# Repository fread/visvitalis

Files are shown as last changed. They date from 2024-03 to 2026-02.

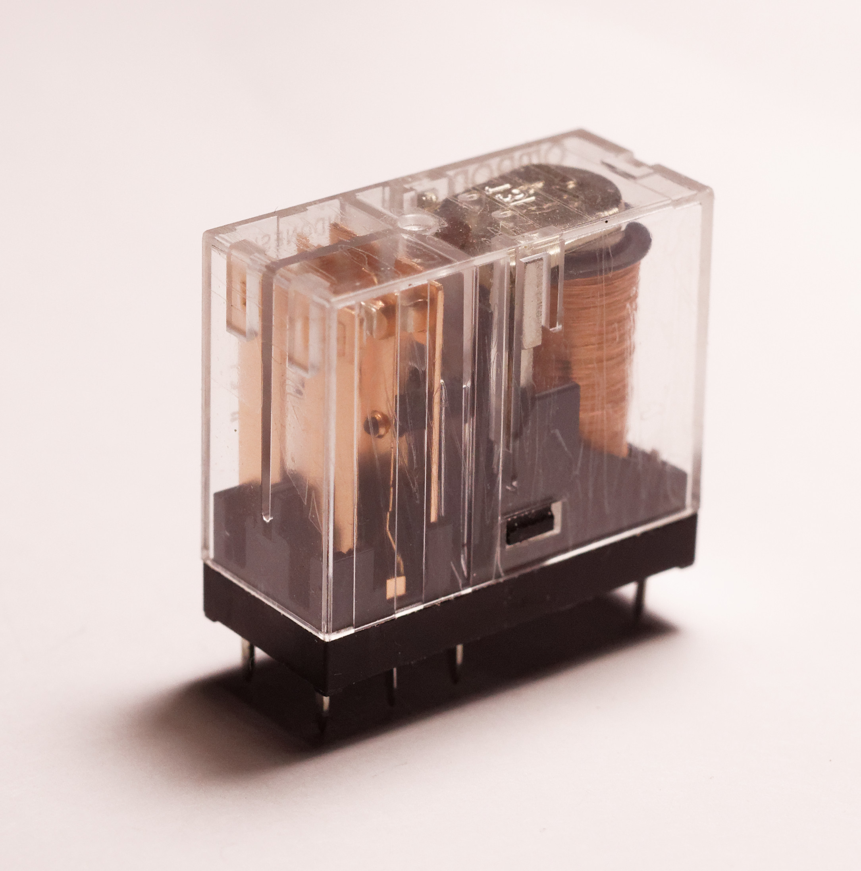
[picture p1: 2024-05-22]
docs/present/img/relay-transparent.jpg

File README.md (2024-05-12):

# vis vitalis - A very simple modular relay processor

This project contains plans for [PCB modules](/new-parts/) to build a relay processor, complete with [assembler](/assembler/) and [emulator](/emulator/).
While the actual processor is made out of relays (and the occasional diode), memory is emulated by ESP-based boards.
Their [firmware](/mem-esp-firmware/) also provides for loading programs and monitoring memory contents via a USB-TTY connection.

## Why though?

Processors are, fundamentally, not *that* complicated.
At any rate, you can build one out of much less than the billions of transistors required for a desktop CPU.
And it's a worthwhile endeavour, too, being actually able to understand a whole processor, albeit a very simple one.

### But why the name?

*vis vitalis*, meaning “force of life”, was a concept in early chemistry.
When it was first discovered that everything is made up of the same elements, people would not accept that this also applies to living beings.
Thus, they postulated the *vis vitalis* as a peculiar element present in everything living, unable to be replicated outside of biological processes.

Today, of course, we know that there is no fundamental difference at all between Turing-complete electronics and any others.

## The modules

Individually, each module performs a simple task – the trick is in how to put them together, for which see below.

In the module description, we use the usual tri-state convention for signal levels: `0` and `1` are signals actively driven low or high respectively, and `Z` is high-impedance, i. e. an unconnected signal.
In some cases, `0` and `Z` are interchangable but most modules require actively driven `0` signals at their inputs to work.

The modules are connected with 10-way ribbon cables carrying eight bits of data as well as 12V positive supply and ground.
Thus, not every module needs its own power supply connection.
Only modules which either draw a lot of current, or which require a stable supply, have a separate power connection.

### 8mux

An eight-bit multiplexer.
If the *select* input is `0` or `Z`, input *in 0* is connected to *out*.
If *select* is `1`, *in 1* is connected to *out*.

The multiplexer passes through signals between the connected terminals in both directions, though from a logical point of view the signals will almost always “flow” from *in* to *out*.

### add

Outputs the sum of *A in*, *B in*, and *carry in* on *A+B out* and *carry out*.
Note that the A operand and the carry bit is also required inverted (*A̅ in* and *c̅a̅r̅r̅y̅ in*).
All inputs must be `0` or `1`, and all outputs will be `0` or `1`.

For normal addition, set *carry in* to `0` and *c̅a̅r̅r̅y̅ in* to `1`.
If you want to subtract rather than add, invert the B and carry inputs (i. e. *carry in* = `1`, *c̅a̅r̅r̅y̅ in* = `0`).

#### Acknowledgement

This design of adder goes back to Konrad Zuse himself, I was made aware of it by the documentation of the
[RelaySBC](https://relaysbc.sourceforge.net/circuits.html) and this
[collection of relay circuits](https://tams.informatik.uni-hamburg.de/applets/hades/webdemos/05-switched/20-relays/zuseadd.html).
Its advantage is that there is no cascading from one relay to another.
All the relays switch in parallel and only steer the inverted and non-inverted signals around.

### clk

The clock generator.
With the values indicated in the schematic, and not populating R3–R6 (again, as indicated), the clock runs at a bit less than 1 Hz.
Populating R3 and R4 with a value of 1 to 15 kΩ slows down the clock, and populating R5 and R6 speeds it up.

#### Acknowledgement

This design was found with some shrewd (or so I'd like to think) internet research.
It originates from https://imgur.com/iKWSAM1.

### decode

In some sense, the instruction decoder is the heart of the processor, though this one mainly distributes the bits of the incoming instruction (*insn in*) to the control outputs (*control out*).

Other than that, it only performs a small assortment of simple logic:
- Relay K1 produces the clock pulses for the `p enable` and `a enable` outputs (to write the the corresponding registers)
- Relays K2, K3, and K5 implement a one-bit register for the carry flag to save the result of the last addition or subtraction.
  The carry register is written whenever the *adder* control signal is `1`.
- The other relays evaluate jump instructions.
  If the current instruction is a jump, they compare the current state of the flags (including the carry register) with the condition called for by the jump.
  They then output the decision to jump or to continue with the next instruction on *pc src out*.

Flag inputs must be `0` or `1`.
Instruction bit 5 must be `0` or `1`. 
The other bits may use `Z` instead of `0`, in which case the corresponding control output is also `Z`.

### disp

This module may be inserted into any data connection to view its current state.
It displays `Z` as `0`.

### flags

This module examines its input for three conditions, and outputs them:
- *odd*: The lowest bit of the input is set
- *sign*: The highest bit of the input is set
- *zero*: The input is zero

Inputs to this module may be `Z`, but then the *odd* and *sign* outputs will also be `Z`, which will not work with the *decode* module.

### inc

Increments the input *A in* and outputs the result on *A+1 out*.
Incrementers may be chained using the *carry in* and *carry out* connections.
The carry input of the first incrementer in a chain (or a standalone incrementer) must be tied to `1`.
This may be done by closing the solder bridge JP1.
In this case, *carry in* should be left unconnected.

All inputs must be `0` or `1`, and all outputs will be `0` or `1`.

### inv

The output *A̅ out* is the bitwise complement of *A in*.
Input values `0` and `Z` map to `1`, and `1` maps to `0`.

### jnc

Just a junction box.

### mem-esp

This module simulates both the program and the data memory.
From the processor's perspective, the program memory is an 8×16 bit ROM, and the data memory is an 8×8 bit RAM.
In addition, it has a USB-TTY connection, so that the memories may be loaded and monitored from a host computer.
Refer to the [documentation in the firmware directory](/mem-esp-firmware/README.md) for how to operate the TTY console.

The *addr in* input takes the address of the data to be read or written.
The *data1 i/o* connection operates either as an input or as an output, depending on the signal at the *w/r̅* input.
*data2 out* is always an output.

If the module is used as ROM, the input side of input no. 1 may not be populated (i. e., leaving out U3, U4, and R1–R16).
If the module is used as an 8×8 bit memory, the second output may not be populated (i. e., leaving out J8, U9, C9–C13).
In this case, the solder bridge JP4 needs to be closed in order to complete the SPI chain.

#### Operation

If the *w/r̅* input is `0` or `Z`, the module operates in read mode.
The output drivers at the *data1 i/o* and (if populated) *data2 out* connections will be active, and output the data found in memory at the address present at the *addr in* input.
The output changes asynchronously with the clock signal, but after a short delay to smooth out any glitches while switching.

If the *w/r̅* input is `1`, the module operates in write mode.
The output drivers are not active, and *data1 i/o* operates as an input.
At the clock's rising edge, the firmware starts sampling the state of *data1 i/o*.
At the clock's falling edge, it updated the memory contents.
For each bit, the most majority value seen in the samples is used, again to smooth out glitches and to account for propagation delays.
`Z` inputs are taken as `0`.

The switch between read and write mode occurs asynchronously.
As soon as the signal at the *w/r̅* input changes, the drivers are activated or deactivated.
Make sure that no signals are sent to the memory module in read mode.
This will lead to an overcurrent condition, and may damage parts.

### nor

This module implements a NOR gate.
For each bit of *A in* and *B in*, the corresponding output bit is `0` if any input is `1`, otherwise (both inputs `0` or `Z`) it is `1`.

### reg

This module is an eight-bit register.
While the *clock* input is `1`, it samples the value of the *in* input.
On the falling edge of the *clock* input (either to `0` or to `Z`), the sampled data is transferred to the buffer stage, and the outputs *out* and *o̅u̅t̅* (inverted) are updated.

The *override* input may be used to asnychronously set bits.
In normal operation, all bits should be `Z`.
Setting them to `0` or `1` causes the corresponding output to change immediately.
Since there are no resistors in the override path, bits should be set one or a few at a time.

### shr

This module shifts its input to the right by one bit.
It contains no logic.

### switch

This module may be used to provide inputs to a partial setup of other modules for testing purposes, or to override a register.
If it is used for overriding a register, it needs switches with a stable center position in order to provide `Z` outputs.

## The whole thing

[See the module schematic.](./docs/schematic.svg)

## Errata

- The LEDs specified on the *disp* and *switch* modules are way too bright in this configuration, even when increasing the series resistors to 2.2 kΩ.
- On the *reg* module, you may want to use larger input resistors (R9–R16) to lower the peak current at the beginning of the write cycle (clock rising edge).
- You may want to exchange the pin headers for control signals for sockets. Then you can use a simple wire in a pinch instead of requiring a jumper with sockets on either end.

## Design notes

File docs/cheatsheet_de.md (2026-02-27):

# Instruktionen

## Berechnen

In der folgenden Liste bedeutet:

* **A** der Inhalt des Akku-Registers
* **P** der Inhalt des Pointer-Registers
* **M[a]** der Inhalt des Speichers an der Adresse **a**

| Insn | Code | Beschreibung |
|---|---|---|
| `a2p` | P = A | Kopiere Akku in Pointer |
| `add x`  | A = A + M[x] | Addiere Variable zu Akku |
| `addi x` | A = A + x | Addiere Wert zu Akku |
| `addp` | A = A + M[P] | Addiere Pointer-Ziel zu Akku |
| `clm x`  | M[x] = 0 | Setze Variable auf 0 |
| `clmp` | M[P] = 0 | Setze Pointer auf 0 |
| `la x` | A = M[x] | Lade Variable in Akku |
| `lai x`  | A = x | Lade Wert in Akku |
| `lap` | A = M[P] | Lade Pointer-Ziel in Akku |
| `lp x` | P = M[x] | Lade Variable in Pointer |
| `lpi x`  | P = x | Lade Wert in Pointer |
| `lpp` | P = M[P] | Lade Pointer-Ziel in Pointer |
| `nor x`  | A = A NOR M[x] | Berechne NOR zwischen Akku und Variable |
| `nori x` | A = A NOR x | Berechne NOR zwischen Akku und Wert |
| `norp` | A = A NOR M[P] | Berechne NOR zwischen Akku und Pointer-Ziel |
| `nop` | | Tu nichts |
| `shr` | A = A >> 1 | Schiebe Akku ein Bit nach rechts |
| `shrs x` | M[x] = A = A >> 1 | Schiebe Akku ein Bit nach rechts und speichere in Variable |
| `sta x`  | M[x] = A | Speichere Akku in Variable |
| `stap` | M[P] = A | Speichere Akku in Pointer-Ziel |
| `stip x` | M[P] = x | Speichere Wert in Pointer-Ziel |
| `sub x`  | A = A - M[x] | Subtrahiere Variable von Akku |
| `subi x` | A = A - x | Subtrahiere Wert von Akku |
| `subp` | A = A - M[P] | Subtrahiere Pointer-Ziel von Akku |

## Springen

| Insn. | Beschreibung |
|---|---|
| `jmp x` | Springe zu x |
| `jc x`  | Springe zu x wenn Carry gesetzt |
| `jge x` | Springe zu x wenn Carry gesetzt |
| `jnc x` | Springe zu x wenn Carry nicht gesetzt |
| `jl x`  | Springe zu x wenn Carry nicht gesetzt |
| `js x`  | Springe zu x wenn Akku negativ ist |
| `jns x` | Springe zu x wenn Akku nicht negativ ist |
| `jz x`  | Springe zu x wenn Akku 0 ist |
| `jnz x` | Springe zu x wenn Akku nicht 0 ist |
| `jev x` | Springe zu x wenn Akku gerade ist |
| `jod x` | Springe zu x wenn Akku ungerade ist |
| `jp` | Springe zu P |
| `jcp` | Springe zu P wenn Carry gesetzt |
| `jncp`  | Springe zu P wenn Carry nicht gesetzt |
| `jsp` | Springe zu P wenn Akku negativ ist |
| `jnsp`  | Springe zu P wenn Akku nicht negativ ist |
| `jzp` | Springe zu P wenn Akku 0 ist |
| `jnzp`  | Springe zu P wenn Akku nicht 0 ist |
| `jevp`  | Springe zu P wenn Akku gerade ist |
| `jodp`  | Springe zu P wenn Akku ungerade ist |

## Illegale Instruktionen

Opcodes dürfen selbst zusammengebaut werden. Manche tun sinnvolle Dinge.

| Bit | wenn 0 | wenn 1 | Bemerkungen |
|-----|---|---|---|
| 7 | | Ergebnis in Speicher schreiben | wenn Bits (7, 6, 5) == 000: Sprung |
| 5 | | Ergebnis in P schreiben | |
| 5 | | Ergebnis in A schreiben | |
| 4 | Ergebnis von Operand/A  | Ergebnis von ALU | |
| 3 | Ergebnis von Operand | Ergebnis von A | wenn Bit 4 == 0 |
| 3 | ALU Shift/Add | ALU NOR/Subtract | wenn Bit 4 == 1 |
| 2 | ALU Shift/NOR | ALU Add/Subtract | 00: Shift, 01: Add, 10: NOR, 11: Sub |
| 1 | Operand aus Speicher | Operand aus Instruktion | "Immediate" |
| 0 | Adresse aus Instruktion | Adresse aus P | "indirekt" |

z. B. `0x5a 1`: P = A - 1

Bei Sprüngen gibt es keine illegalen Instruktionen, alle möglichen Instruktionen haben Mnemonics.

# Programmieren

## `uint8_t x;`
Adressen für Variablen mit `.equ` vergeben.
```asm
.equ x 23
```

## `x = 5;`
```asm
lai 5
sta x
```

## `x = y;`
```asm
la y
sta x
```

## `a = b + c`
```asm
la a
add b
sta c
```

## `if (x >= y) goto z;`
Für `jc` Und `jnc` gibt es die suggestiv benannten alternativen Mnemonics `jge` und `jl`:
```asm
la x
sub y
jge z
```

## `if (x < y) goto z;`
```asm
la x
sub y
jl z
  ```

## `while (x != 0) { xxx } yyy`
```asm
loop:
  la x
  jz end
  xxx
  jmp loop
end:
  yyy
  ...
```

## `x = a[i]`
```asm
la a
add i
a2p
lp
sta x
```

## `a[i] = x`
```asm
la a
add i
a2p
la x
stp
```

# Projektideen

* Lauflicht (hin und her?)
* Fibonacci
* Maximum suchen
* {mem,str}{cpy,chr,mem,str,...}
* Array umdrehen
* Multiplikation
* Binäre Suche
* Illegale Instruktionen ausprobieren
* Division
* Fizzbuzz
* Call/Return
* RPN-Evaluator

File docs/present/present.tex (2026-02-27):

\documentclass[t,aspectratio=169,usenames,dvipsnames]{beamer}

\graphicspath{{img/}}

\usepackage{mathspec}

\usepackage{algorithm}
\usepackage{algpseudocode}
\usepackage{booktabs}
\usepackage[ngerman]{babel}
\usepackage{cancel}
\usepackage{changepage}
\usepackage{collect}
\usepackage{comment}
\usepackage{csquotes}
\usepackage{float}
\usepackage{graphbox}
\usepackage{hyperref}
\usepackage{listings}
\usepackage{multimedia}
\usepackage{tikz}
\usepackage[table]{xcolor}
\usepackage{siunitx}
\usepackage{arev}
\usepackage{qrcode}

% \setmainfont{Libertinus Serif}
% \setsansfont{Libertinus Sans}
% \setmonofont{TeX Gyre Cursor Bold}
% \setmathfont[Digits]{Libertinus Sans}

\setmainfont{Liberation Serif}
\setsansfont{Liberation Sans}
\setmonofont{Liberation Mono}
\setmathfont[Digits]{Liberation Sans}

\usetheme{Madrid}
\usecolortheme{dove}
\setbeamercovered{invisible}
\setbeamercolor{alerted text}{fg=blue}

\setbeamertemplate{navigation symbols}{}

\newenvironment{itemblock}[1]{\begin{block}{#1}\begin{itemize}}{\end{itemize}\end{block}}
\newenvironment{withtitle}[1]{\begin{description}\item[#1]~\\}{\end{description}}

\newcommand{\todo}[1]{\colorbox{red}{\color{white}\bf TODO: #1}}
\newcommand{\dunno}[0]{\colorbox{red}{\color{white}\bf ???}}

\newcommand{\uexplain}[2]{\underbrace{\mathtt{#1}}_{\hidewidth \mathsf{#2}\hidewidth} \hskip 0.5em}
\newcommand{\oexplain}[2]{\overbrace{\mathtt{#1}}^{\hidewidth \mathsf{#2}\hidewidth} \hskip 0.5em}

\newcommand{\extraslide}{\textcolor{orange}{$\warning$}}

\definecollection{picture-sources}

\newcommand{\sourcedimage}[5][width=\textwidth,height=0.7\textheight,keepaspectratio]{%
  \begin{center}
    

    \expandafter\begin{collect}{picture-sources}{}{}
      \item[#3] \href{#4}{#4} \\ #5
    \end{collect}
  \end{center}
}

\newcommand{\imageframe}[4]{%
  {
    \setbeamercolor{background canvas}{bg=black}
    \begin{frame}[c,plain]
        \expandafter\begin{collect}{picture-sources}{}{}
        \item[#2] \href{#3}{#3} \\ #4
        \end{collect}
        \begin{tikzpicture}[remember picture,overlay]
          \node[at=(current page.center)] {
            
          };
        \end{tikzpicture}
    \end{frame}
  }
}

\lstset{basicstyle=\ttfamily}

\renewcommand{\algorithmicforall}{\textbf{for each}}

\title[~]{\Huge Computer selbst bauen}
\subtitle{}
\author[~]{andi $\langle$andi@entropia.de$\rangle$}
\date{}

\begin{document}

{
  \setbeamercolor{background canvas}{bg=black}
  \begin{frame}[plain]
    \begin{tikzpicture}[remember picture,overlay]
      \node[at=(current page.center)] {
        
      };
    \end{tikzpicture}
  \end{frame}
}

\begin{frame}
  \frametitle{Es ist kompliziert}

  \begin{columns}
    \begin{column}{.45\textwidth}
      \begin{center}
        \sourcedimage{zen2-die-shot}{Die Shot eines AMD Zen2}{https://en.wikipedia.org/wiki/File:Zen2\_Matisse\_Ryzen\_7nm\_Core\_Die\_shot.jpg}{Fritzchens Fritz, 2019. CC-0.}
        \emph{AMD Zen 2 \enquote{Matisse}}
      \end{center}
    \end{column}
    \begin{column}{.45\textwidth}
      \begin{itemize}
      \item \qty{4800000000} Transistoren
      \item Taktzeit:\\
        \qty{0.2}{\nano\second} $\hat=$ \qty{6.4} Licht-cm $\approx$ \qty{4} Strom-cm
      \end{itemize}
    \end{column}
  \end{columns}
\end{frame}

\begin{frame}
  \frametitle{Es geht einfacher}

  \begin{columns}
    \begin{column}{.45\textwidth}
      \sourcedimage{relay-transparent}{Transparentes Relais}{https://commons.wikimedia.org/wiki/File:Omron\_G2R-2-24V\_relay\_04.jpg}{Retired electrician, 2022. CC-0.}
    \end{column}
    \begin{column}{.45\textwidth}
      \begin{itemize}
      \item \qty{120} Relais
      \item Takt: $\approx$ \qty{1}{\second}
      \end{itemize}

      \bigskip\pause

      \begin{itemize}
      \item auch binäre Schaltung (sort of)
      \item Kann auch Logik-Gates implementieren
      \item Details: ignorieren wir
      \end{itemize}
    \end{column}
  \end{columns}
\end{frame}

\begin{frame}
  \frametitle{Thinking with Modules}

  \strut{}\alt<2>{So sehen wir es:}{So sieht es eigentlich aus:}

  \bigskip

  \alt<2>{
    \centering

    \bigskip

    \begin{itemize}
    \item 8 Signale auf einmal\\
      \emph{nur} in unserem Kopf eine Zahl, Adresse, \ldots
    \item Funktionalität in Module zusammengefasst\\
      Bits rein, Bits raus, dazwischen Magie
    \end{itemize}
  }{
    \centering
  }

\end{frame}

% \begin{frame}
%   \frametitle{0, 1, Logik}

%   \begin{center}
%     MOSFET, BJT, Röhren, Ringkerne, Opamps, Relais, Hydraulik, Lochbleche, \ldots

%     \textit{Alles das Gleiche und sowieso nur Gefrickel!}
%   \end{center}

%   \begin{columns}[t]
%     \begin{column}{.45\textwidth}
%       \begin{block}{Signale}
%         \begin{itemize}
%         \item binärer Rechner $\Rightarrow$ 0 und 1
%         \item Signalübertragung (also Kabel \ldots)
%         \end{itemize}
%       \end{block}
%     \end{column}
%     \begin{column}{.45\textwidth}
%       \begin{block}{Gates}
%         Beliebige Gates sind erlaubt, spezifiziert durch \enquote{kleine} I/O-Tabelle

%         \begin{center}
%           \begin{tabular}{ccc}
%             X & Y & out \\
%             \midrule
%             0 & 0 & 1 \\
%             0 & 1 & 0 \\
%             1 & 0 & 0 \\
%             1 & 1 & 0 \\
%           \end{tabular}
%         \end{center}
%       \end{block}
%     \end{column}
%   \end{columns}
% \end{frame}

% \begin{frame}
%   \frametitle{Busse}

%   \begin{columns}[T]
%     \begin{column}{.45\textwidth}
%       \begin{itemize}
%       \item Signale gehören zusammen und tun \enquote{das Gleiche}
%       \item übersichtlicher mit einer Linie\\
%         (1 fette Linie $\hat=$ 8 dünne)\\
%         und einem Gate
%       \item nur (!) in unserem Kopf:\\
%         Zahl, Adresse, Instruktion \ldots
%       \end{itemize}
%     \end{column}

%     \begin{column}{.45\textwidth}
%       \centering\includegraphics[height=.75\textheight]{nor-bus.pdf}
%     \end{column}
%   \end{columns}
% \end{frame}

\begin{frame}[c]
  \frametitle{Rechnen ist nicht schwer}

  \strut{}Zwei Eingänge für zwei Operanden, im Prinzip nicht schwieriger, nur mehr Hardware

  \bigskip

  \centering
\end{frame}

\begin{frame}
  \frametitle{\extraslide{} OK, vielleicht nicht ganz so simplel}

  \begin{columns}
    \begin{column}{.45\textwidth}
      \begin{align*}
        0 + 0 + 0 = 00 \\
        0 + 0 + 1 = 01 \\
        0 + 1 + 0 = 01 \\
        1 + 0 + 0 = 01 \\
        1 + 1 + 0 = 10 \\
        \textcolor<2->{RoyalBlue}{1 + 0 + 1 = 10} \\
        0 + 1 + 1 = 10 \\
        1 + 1 + 1 = 11
      \end{align*}

      Drei Eingänge, zwei Ausgänge, aber auch nur ein Gate!
    \end{column}
    \begin{column}{.45\textwidth}
      \begin{center}
        \alt<2->{
          \begin{tabular}{ccccccccc}
            & 0 & 0 & 1 & 1 & \cellcolor{SkyBlue}1 & 1 & 1 & 0 \\
            + & 0 & 0 & 0 & 1 & \cellcolor{SkyBlue}0 & 1 & 0 & 1 \\
            &   &   & \scriptsize{1}  & \cellcolor{SkyBlue}\scriptsize{1}  & \cellcolor{SkyBlue}\scriptsize{1}  &   &   &   \\
            \hline
            & 0 & 1 & 0 & 1 & \cellcolor{SkyBlue}0 & 0 & 1 & 1
          \end{tabular}
        }{
          \begin{tabular}{ccccccccc}
            & 0 & 0 & 1 & 1 & 1 & 1 & 1 & 0 \\
            + & 0 & 0 & 0 & 1 & 0 & 1 & 0 & 1 \\
            &   &   & \scriptsize{1}  & \scriptsize{1}  & \scriptsize{1}  &   &   &   \\
            \hline
            & 0 & 1 & 0 & 1 & 0 & 0 & 1 & 1
          \end{tabular}
        }

        \bigskip

        \uncover<3>{
          
        }
      \end{center}
    \end{column}
  \end{columns}

\end{frame}

\begin{frame}
  \frametitle{\extraslide{} Auftritt Zuse}

  \begin{columns}[T]
    \begin{column}{.50\textwidth}
      \begin{tabular}{ccc@{\hskip 2em}c@{\hskip 2em}cc}
        \toprule
        $A$ & $B$ & $C_{\text{in}}$ & \uncover<2->{$A \oplus B$} & $A + B + C_{\text{in}}$ & $C_{\text{out}}$ \\
        \midrule
        0 & 0 & 0 & \uncover<2->{0} & \alt<3->{$C_{in}$}{0}      & \alt<4->{$A$}{0}      \\
        0 & 0 & 1 & \uncover<2->{0} & \alt<3->{$C_{in}$}{1}      & \alt<4->{$A$}{0}      \\
        0 & 1 & 0 & \uncover<2->{1} & \alt<3->{$\neg C_{in}$}{1} & \alt<4->{$C_{in}$}{0} \\
        0 & 1 & 1 & \uncover<2->{1} & \alt<3->{$\neg C_{in}$}{0} & \alt<4->{$C_{in}$}{1} \\
        1 & 0 & 0 & \uncover<2->{1} & \alt<3->{$\neg C_{in}$}{1} & \alt<4->{$C_{in}$}{0} \\
        1 & 0 & 1 & \uncover<2->{1} & \alt<3->{$\neg C_{in}$}{0} & \alt<4->{$C_{in}$}{1} \\
        1 & 1 & 0 & \uncover<2->{0} & \alt<3->{$C_{in}$}{0}      & \alt<4->{$A$}{1} \\
        1 & 1 & 1 & \uncover<2->{0} & \alt<3->{$C_{in}$}{1}      & \alt<4->{$A$}{1}      \\
        \bottomrule
      \end{tabular}
    \end{column}
    \begin{column}{.45\textwidth}
      \begin{itemize}
      \item Wie geht das besser?
        \pause
      \item Es muss etwas mit XOR zu tun haben
        \pause
      \item $A + B = \begin{cases}
                       C_{in} & A \oplus B = 0 \\
                       \neg C_{in} & A \oplus B = 1 \\
                     \end{cases}$
        \pause
      \item $C_{out} = \begin{cases}
                         A & A \oplus B = 0 \\
                         C_{in} & A \oplus B = 1 \\
                       \end{cases}$
        \pause
        \bigskip
      \item Nur $A$ und $B$ fließen in Logik ein!
      \item Kein Ripple mehr!
      \end{itemize}
    \end{column}
  \end{columns}
\end{frame}

\begin{frame}
  \frametitle{Ist das nicht schon alles?}

  \begin{columns}
    \begin{column}{.45\textwidth}
      \begin{center}
        

        \[ x_1 = \frac{-b + \sqrt{b^2 - 4ac}}{2a} \]
      \end{center}
    \end{column}
    \begin{column}{.45\textwidth}
      \uncover<2->{
        Nein, es fehlt \ldots
        \begin{itemize}
        \item \textbf{Auswahl}\\
          $x_2$ ohne Neuverkabeln
        \item \textbf{Speicher}\\
          $a$, $b$, $c$ weg $\Rightarrow$ $x$ weg\quad :(
        \item \textbf{Programm}\\
          \texttt{goto}, \texttt{if}, \texttt{while}, \texttt{for}, \texttt{func}, \ldots
        \end{itemize}
      }
    \end{column}
  \end{columns}
\end{frame}

\begin{frame}
  \frametitle{1/3: Auswahl}

  Wichtigstes Modul: \textbf{Multiplexer} (Spitzname: Mux)

  \begin{columns}
    \begin{column}{.45\textwidth}
      \begin{center}
        
      \end{center}
    \end{column}
    \begin{column}{.45\textwidth}

      \textbf{s} ist nur ein Bit
      \begin{itemize}
      \item $\mathbf{s} = 0$:\\
        Eingang 0 mit Ausgang verbunden
      \item $\mathbf{s} = 1$:\\
        Eingang 1 mit Ausgang verbunden
      \end{itemize}

      \bigskip

      Von zwei Bytes eins auswählen

    \end{column}
  \end{columns}
\end{frame}

\begin{frame}
  \frametitle{Fast eine ALU}

    \begin{columns}[T]
    \begin{column}{.45\textwidth}
        \only<1>{}
        \only<2>{}
    \end{column}
    \begin{column}{.45\textwidth}
      Prinzip: Erst rechnen, dann aussuchen

      \bigskip

      \textbf{Kontrollsignale}

      \begin{itemize}
      \item Steuern Datenfluss, bei uns vor allem an Multiplexern
      \item Jetzt: \enquote{Schalter}
      \item Später: Programmieren
      \end{itemize}

      \bigskip

      \only<2>{
        \begin{itemize}
        \item Mehr Möglichkeiten: Mux-Baum bauen
        \item nicht \emph{ganz} realistisch
        \end{itemize}
      }
  \end{column}
  \end{columns}
\end{frame}

\begin{frame}
  \frametitle{2/3: Speicher}

  Details ignorieren wir wieder (irgendwas mit Kondensatoren und Hysterese)

  \bigskip

  

  \bigskip

  \enquote{write}-Signal wird Systemtakt/-clock sein
\end{frame}

\begin{frame}[c]
  \frametitle{\extraslide{} Doch mit Details}

  \begin{columns}[c]
    \begin{column}{.45\textwidth}
      
    \end{column}
    \begin{column}{.45\textwidth}
      \begin{itemize}
      \item Was ist Hysterese?
        \begin{itemize}
        \item über ca. 9~V: an
        \item unter ca. 2~V: aus
        \item dazwischen: nichts passiert
        \end{itemize}

      \item K2 auf ca. ½ VCC \\
        $\Rightarrow$ hält Zustand

        \bigskip

      \item Clock-Phasen:
        \begin{itemize}
        \item High: d\_in lädt C1 auf GND/VCC
        \item Low: Puls von C1 bringt K2 über 9~V oder unter 2~V
        \end{itemize}
      \end{itemize}
    \end{column}
  \end{columns}

\end{frame}

\begin{frame}
  \frametitle{Speicher × 8}

  \begin{columns}[T]
    \begin{column}{.45\textwidth}
      
    \end{column}
    \begin{column}{.45\textwidth}
      \begin{itemize}
      \item erstes Modul mit Takt\\
        (Kennzeichnung mit {\Large$\triangleright$})
      \item nicht immer jedes Register überschreiben\\
        $\Rightarrow$ \emph{Clock-Gate}
      \item Kontrollsignal \enquote{A enable}
      \end{itemize}
    \end{column}
  \end{columns}

\end{frame}

\begin{frame}
  \frametitle{\emph{mehr} Speicher}

  \begin{columns}
    \begin{column}{.7\textwidth}
      
    \end{column}
    \begin{column}{.25\textwidth}
      \uncover<2>{Das wird \emph{groß}...}
    \end{column}
  \end{columns}

\end{frame}

\begin{frame}
  \frametitle{Leider gecheatet}

  \begin{itemize}
  \item 1 Register ${} \mathrel{\hat=} \qty{5}{\centi\metre} \times \qty{10}{\centi\metre}$
  \item 256 Register ($16 \times 16$) ${} \mathrel{\hat=} \qty{80}{\centi\metre} \times \qty{160}{\centi\metre}$
  \item \ldots von den Muxen ganz zu schweigen
  \end{itemize}

  \bigskip

  $\Rightarrow$ Geht nur mit ICs

  \bigskip

  Außerdem:
  \begin{itemize}
  \item Programme Laden
  \item Debugging
  \item Speichermonitor
  \end{itemize}

\end{frame}

\begin{frame}
  \frametitle{RAM}

  \begin{itemize}
  \item In jedem Takt Lesen \emph{oder} Schreiben
  \item Daten-Anschluss ist bidirektional $\Rightarrow$ etwas verdächtiger Mux
  \end{itemize}

  \bigskip

  \begin{center}
    
  \end{center}
\end{frame}

\begin{frame}
  \frametitle{Jetzt geht's los}

  Alles beisammen:

  \bigskip

  \renewcommand{\arraystretch}{3.5}

  \begin{tabular}{clc>{\qquad}clc}
    \setcounter{enumi}{1}\usebeamertemplate{enumerate item}
    & Berechnungen
    & 
    & \setcounter{enumi}{1}\usebeamertemplate{enumerate item}
    & Speicher
    &  \\

    \setcounter{enumi}{2}\usebeamertemplate{enumerate item}
    & Multiplexer
    & 
    & \setcounter{enumi}{5}\usebeamertemplate{enumerate item}
    & \multicolumn{2}{l}{???\qquad{}\uncover<2>{\textbf{Sie befinden sich hier}}}
    \\

    \setcounter{enumi}{3}\usebeamertemplate{enumerate item}
    & Register
    & 
    & \setcounter{enumi}{6}\usebeamertemplate{enumerate item}
    & \cancel{Profit} Prozessor
    &
  \end{tabular}
\end{frame}

\begin{frame}
  \frametitle{\extraslide{} Assembler}

  Wie sollen Instruktionen aussehen?
  \begin{itemize}
  \item Wie RISC (ARM, RISC-V, MIPS, SPARC, \ldots): \texttt{add r3, r2, r1}\\
    16/32 Register, 3 Register in jeder Instruktion, Laden/Speichern anderes Format
  \item Wie x86: \texttt{addq \%rsi, 42(\%rbx, \%rcx, 4)}\\
    Nein
  \item Wie 6502: \texttt{lda \$23; adc \$42}\\
    4(?) Register, 1 Operand, (fast) immer genau ein Speicherzugriff\\
    \pause
    \textbf{Das klingt gut!}
  \end{itemize}

  \bigskip

  Unser Plan:
  \begin{itemize}
  \item Opcode + 1 Operand
  \item wenige Register
  \item einmal Laden/Speichern pro Instruktion
  \end{itemize}

\end{frame}

\begin{frame}
  \frametitle{Akkumulator-Architektur}

  \begin{itemize}
  \item Instruktion = Operation + Operand
  \item \emph{ein einziges} Register (\texttt{A})
  \item alle Berechnungen \enquote{\texttt{A} = \texttt{A} $\circledast$ Speicher}
  \item ein Speicherzugriff pro Instruktion $\checkmark$
  \end{itemize}

  \bigskip

  \texttt{z = x + y;} wird zu

  \bigskip

  {\Large
    \texttt{load~~\&x} \qquad \texttt{A = x};\\
    \texttt{add~~~\&y} \qquad \texttt{A = A + y;}\\
    \texttt{store~\&z} \qquad \texttt{z = A;}\\
  }
\end{frame}

\begin{frame}
  \frametitle{\extraslide{} Plus/Minus}

  Addition und Subtraktion sind fast das Gleiche:
  \begin{align*}
    A - B &= A + (-B) \\
          &= A + (\neg B + 1) \\
          &= A \mathop{+} \neg B + 1_{\text{carry-in}}
  \end{align*}

  Also: $B$ negieren und ein Carry eingeben.
  \begin{align*}
    A \pm B &= A + \left\lbrace \begin{aligned} B \\ \neg B \end{aligned} \right\rbrace + \left\lbrace \begin{aligned} 0_{\text{carry-in}} \\ 1_{\text{carry-in}} \end{aligned} \right\rbrace\\
  \end{align*}
\end{frame}

\begin{frame}
  \frametitle{ALU-Aufbau: Rechnungen}

  \strut{}ALU + Write-Back in den Akkumulator

  \begin{center}
    
  \end{center}
\end{frame}

\begin{frame}
  \frametitle{ALU-Aufbau: \texttt{load}}

  \strut{}Ein Weg an der ALU vorbei um Daten in A zu laden

  \begin{center}
    
  \end{center}
\end{frame}

\begin{frame}
  \frametitle{ALU-Aufbau: \texttt{store}}

  \strut{}Operanden kommen aus dem Speicher, Ergebnisse müssen dahin zurück

  \begin{center}
    
  \end{center}
\end{frame}

\begin{frame}
  \frametitle{Immediates}

  Konstanten sind auch wichtig:
  \begin{itemize}
  \item \texttt{answer = secret + 19;}
  \item \texttt{start = 0;}
  \item \texttt{i++}
  \end{itemize}

  \bigskip

  In Assembler \enquote{Immediate}. Operand als Wert, nicht als Adresse

  \medskip

  {\Large
    \begin{tabular}{l@{\hskip 4em}l}
      \texttt{add 19} & \texttt{addi 19} \\
      \texttt{load 0} & \texttt{loadi 0} \\
    \end{tabular}
  }

  \bigskip

  \pause
  Wir brauchen noch ein Mux \ldots\ (es wird nicht das Letzte sein)
\end{frame}

\begin{frame}
  \frametitle{Immediates}

  \strut{}Operand direkt in die ALU geben

  \begin{center}
    
  \end{center}
\end{frame}

\begin{frame}
  \frametitle{Pointer}

  Manchmal sind Adressen nicht konstant:
  \begin{itemize}
  \item \texttt{int *p = lol(); int x = *p;}
  \item \texttt{cpu->bits = 8;}
  \item \texttt{dinge[i] = d;}
  \end{itemize}

  \bigskip

  Adresse in A berechnen und dann Laden/Speichern?\\
  Leider nein: \texttt{*p = x;} braucht \texttt{p} und \texttt{x} gleichzeitig

  \bigskip
  \pause

  Wir brauchen noch ein Mux und ein \emph{Register} \ldots\ (zum Glück das Vorletzte)

\end{frame}

\begin{frame}
  \frametitle{Pointer}

  \strut{}Zweites Register mit Write-Back, Auswahl der Datenadresse

  \begin{center}
    
  \end{center}
\end{frame}

\begin{frame}
  \frametitle{Fertig ist der \emph{Data-Path}}

  \strut{}\alt<2>{\cancel{9} 8}{9} Kontrollsignale steuern alles

  \begin{center}
    \alt<2>{}{}
  \end{center}
\end{frame}

\begin{frame}
  \frametitle{Plötzlich Maschinencode}

  {\centering
    \begin{tikzpicture}
      \node[draw,thick,minimum width=5em,minimum height=5em,align=center] at (0,0) {\footnotesize Speicher\\\footnotesize schreiben};
      \node[draw,thick,minimum width=5em,minimum height=5em,align=center] at (5em,0) {\footnotesize Reg. P\\\footnotesize schreiben};
      \node[draw,thick,minimum width=5em,minimum height=5em,align=center] at (10em,0) {\footnotesize Reg. A\\\footnotesize schreiben};
      \node[draw,thick,minimum width=5em,minimum height=5em,align=center] at (15em,0) {\footnotesize ALU\\\footnotesize benutzen};
      \node[draw,thick,minimum width=5em,minimum height=5em,align=center] at (20em,0) {\footnotesize A lesen\\\footnotesize ——\\\footnotesize \enquote{invertieren}};
      \node[draw,thick,minimum width=5em,minimum height=5em,align=center] at (25em,0) {\footnotesize Addierer\\\footnotesize benutzen};
      \node[draw,thick,minimum width=5em,minimum height=5em,align=center] at (30em,0) {\footnotesize Immediate};
      \node[draw,thick,minimum width=5em,minimum height=5em,align=center] at (35em,0) {\footnotesize Indirekt};
    \end{tikzpicture}
  }

  \begin{itemize}
  \item Eine Mux-Einstellung $\hat=$ ein Bit $\Rightarrow$ 8 in einem Byte zusammenfassen
  \item z.B. \texttt{add}: A schreiben, Ergebnis von der ALU, Addierer benutzen, sonst nichts\\
    $\Rightarrow \mathtt{add} = \text{0b00110100} = \text{0x34}$

    \medskip

  \item Zweites Byte für den Operanden: $\mathtt{add~42} = \text{0x342a}$
  \end{itemize}

  \bigskip

  \pause

  Eine Instruktion = 16 bit $\Rightarrow$ \textbf{Das können wir speichern!}
\end{frame}

\begin{frame}
  \frametitle{Programmspeicher}

  \strut{}Noch ein Speicher für das Programm (\enquote{Harvard})

  \begin{center}
    
  \end{center}
\end{frame}

\begin{frame}
  \frametitle{Program Counter}

  \strut{}Wenn wir doch nur automatisch zählen könnten~\ldots

  \begin{center}
    
  \end{center}
\end{frame}

\begin{frame}
  \frametitle{Sprünge}

  \strut{}Noch ein Mux, die Details sind kompliziert

  \begin{center}
    
  \end{center}
\end{frame}

\begin{frame}
  \frametitle{Was fehlt?}

  Was wir \enquote{Maschinencode} genannt haben sieht sehr nach \emph{Microcode} aus.
  \begin{itemize}
  \item Viele nutzlose Befehle: \enquote{Addiere \texttt{i} auf Inhalt der Adresse \texttt{i}}, anyone?\\
    \texttt{0x96 i}
  \item 3 Bit für Kombination aus \enquote{A schreiben}, \enquote{P schreiben}, \enquote{Speicher schreiben}\\
    Lieber 3 Bit für Auswahl von einer aus 8 Möglichkeiten!

  \end{itemize}

  \bigskip\pause

  \textbf{Decoding!} Kleinere Assembler-Befehle intern zu Steuersignalen auspacken
\end{frame}

\begin{frame}
  \frametitle{Ihr könnt das auch!}

  und zwar einfacher und besser
  \begin{itemize}
  \item Simulationen
    \begin{itemize}
    \item Paul Falstads Circuit Simulator
    \item Logisim(-Evolution)
    \item Turing Complete
    \end{itemize}
  \item FPGAs (jetzt auch in günstig und Open Source)
    \begin{itemize}
    \item Yosys OSS CAD Suite
    \end{itemize}
  \item Chips statt Relais
  \end{itemize}
\end{frame}

\begin{frame}
  \frametitle{Wie geht es weiter}

  Gerät ist im Nebenraum aufgebaut.

  \bigskip

  \begin{description}[ca. 20:00:]
  \item[Jetzt:] Q\&A
  \item[19:00:] Pause, Abendessen
  \item[ca. 20:00:] Assembler-Workshop
  \end{description}
\end{frame}

\begin{frame}
  \frametitle{Repository}
  \begin{center}
    \texttt{https://github.com/fread/visvitalis}

    \bigskip

    \qrcode[height=0.5\textheight]{https://github.com/fread/visvitalis}
  \end{center}
\end{frame}

\begin{frame}
  \frametitle{Assembler}

  \begin{itemize}
  \item Eine Instruktion pro Zeile
  \item (Mnemonic/Opcode) + Argument\\
    \texttt{~~lai 17}\\
    \texttt{~~addi 6}
  \item Werte definieren und benutzen (\texttt{\#define})\\
    \texttt{~~.equ x 2~~~~~~~~\# Adresse einer Variable}\\
    \texttt{~~.equ answer 42~~\# Konstante}\\
    \texttt{~~lai answer}\\
    \texttt{~~sta x~~~~~~~~~~~\# x = 42}\\
  \item Label vor Instruktion mit Doppelpunkt\\
    Expandiert zu Adresse der Instruktion\\
    \texttt{~~loop: subi 1}\\
    \texttt{~~~~~~~~jmp loop}
  \item Alles ein Namensraum
  \end{itemize}
\end{frame}

\begin{frame}
  \frametitle{Bildnachweis}
  \tiny
  \begin{description}
    \includecollection{picture-sources}
  \end{description}
\end{frame}

\end{document}

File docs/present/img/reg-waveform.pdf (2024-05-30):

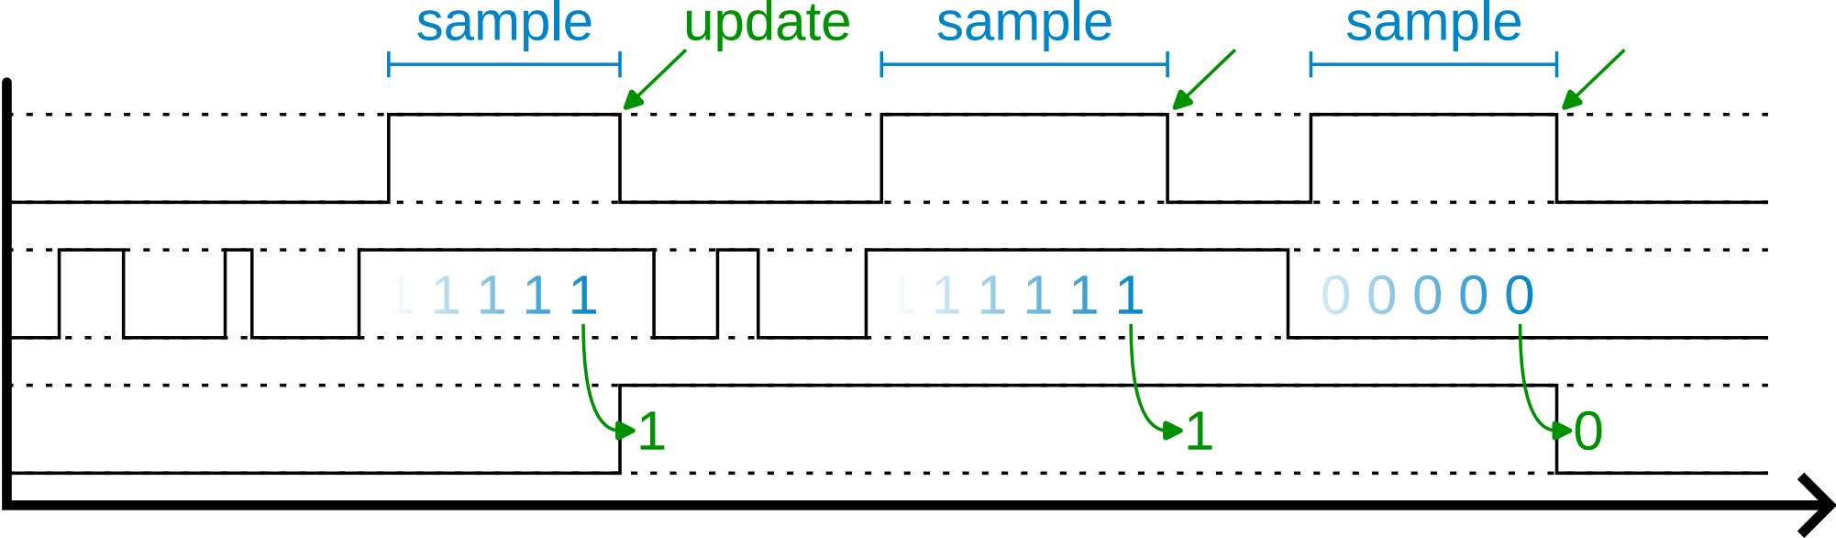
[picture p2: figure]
sample; update

out

in

write

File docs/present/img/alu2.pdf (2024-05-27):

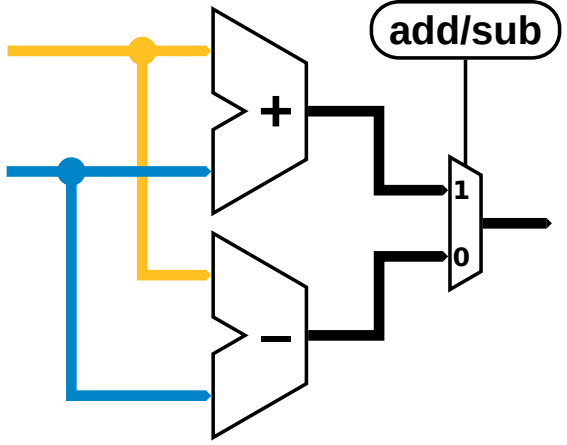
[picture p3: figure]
add/sub

ab

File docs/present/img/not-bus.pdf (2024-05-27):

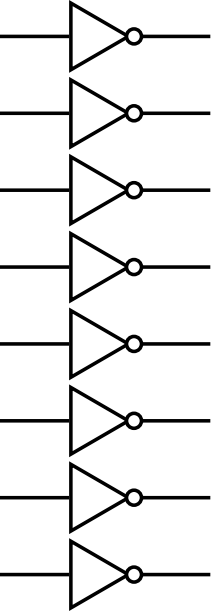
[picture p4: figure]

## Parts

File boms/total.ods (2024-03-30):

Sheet: Sheet1
Part | Value | Footprint | Qty | Total qty | part | copies
8mux | SMAJ14CA | Diode_SMD:D_SMA_Handsoldering | 1 | 9 | 8mux | 9
8mux | BHR-10-VUA | Connector_IDC:IDC-Header_2x05_P2.54mm_Vertical | 3 | 27 | add | 1
8mux | Conn_01x01 | Connector_PinHeader_2.54mm:PinHeader_1x01_P2.54mm_Vertical | 1 | 9 | clk | 1
8mux | J104D2C12VDC.15S | Relay_THT:Relay_DPDT_Finder_30.22 | 4 | 36 | decode | 1
add | SMAJ14CA | Diode_SMD:D_SMA_Handsoldering | 8 | 8 | disp | 5
add | BHR-10-VUA | Connector_IDC:IDC-Header_2x05_P2.54mm_Vertical | 4 | 4 | flags | 1
add | Conn_01x02 | Connector_PinHeader_2.54mm:PinHeader_1x02_P2.54mm_Vertical | 2 | 2 | inc | 1
add | J104D2C12VDC.15S | Relay_THT:Relay_DPDT_Finder_30.22 | 16 | 16 | inv | 1
clk | 470uF | Capacitor_THT:CP_Radial_D10.0mm_P5.00mm | 2 | 2 | jnc | 8
clk | SMAJ14CA | Diode_SMD:D_SMA_Handsoldering | 2 | 2 | Mem-esp | 3
clk | Conn_02x02_Odd_Even | Connector_PinHeader_2.54mm:PinHeader_2x02_P2.54mm_Vertical | 1 | 1 | nor | 1
clk | Conn_01x08 | Connector_PinHeader_2.54mm:PinHeader_1x08_P2.54mm_Vertical | 1 | 1 | reg | 3
clk | J104D2C12VDC.15S | Relay_THT:Relay_DPDT_Finder_30.22 | 2 | 2 | switch | 6
clk | 47R | Resistor_SMD:R_0805_2012Metric_Pad1.20x1.40mm_HandSolder | 2 | 2
decode | 470uF | Capacitor_THT:CP_Radial_D10.0mm_P5.00mm | 1 | 1
decode | SMAJ14CA | Diode_SMD:D_SMA_Handsoldering | 8 | 8
decode | D | Diode_SMD:D_SMA_Handsoldering | 3 | 3
decode | BHR-10-VUA | Connector_IDC:IDC-Header_2x05_P2.54mm_Vertical | 1 | 1
decode | Conn_01x01 | Connector_PinHeader_2.54mm:PinHeader_1x01_P2.54mm_Vertical | 12 | 12
decode | Conn_01x03 | Connector_PinHeader_2.54mm:PinHeader_1x03_P2.54mm_Vertical | 1 | 1
decode | J104D2C12VDC.15S | Relay_THT:Relay_DPDT_Finder_30.22 | 9 | 9
decode | 47R | Resistor_SMD:R_0805_2012Metric_Pad1.20x1.40mm_HandSolder | 1 | 1
decode | 680R | Resistor_SMD:R_0805_2012Metric_Pad1.20x1.40mm_HandSolder | 1 | 1
disp | 151053GS03000 | LED_THT:LED_D5.0mm_Clear | 8 | 40
disp | BHR-10-VUA | Connector_IDC:IDC-Header_2x05_P2.54mm_Vertical | 2 | 10
disp | 750R | Resistor_SMD:R_0805_2012Metric_Pad1.20x1.40mm_HandSolder | 8 | 40
flags | D | Diode_SMD:D_SMA_Handsoldering | 8 | 8
flags | SMAJ14CA | Diode_SMD:D_SMA_Handsoldering | 1 | 1
flags | BHR-10-VUA | Connector_IDC:IDC-Header_2x05_P2.54mm_Vertical | 1 | 1
flags | Conn_01x03 | Connector_PinHeader_2.54mm:PinHeader_1x03_P2.54mm_Vertical | 1 | 1
flags | J104D2C12VDC.15S | Relay_THT:Relay_DPDT_Finder_30.22 | 1 | 1
inc | SMAJ14CA | Diode_SMD:D_SMA_Handsoldering | 8 | 8
inc | BHR-10-VUA | Connector_IDC:IDC-Header_2x05_P2.54mm_Vertical | 2 | 2
inc | Conn_01x01 | Connector_PinHeader_2.54mm:PinHeader_1x01_P2.54mm_Vertical | 2 | 2
inc | J104D2C12VDC.15S | Relay_THT:Relay_DPDT_Finder_30.22 | 8 | 8
inv | SMAJ14CA | Diode_SMD:D_SMA_Handsoldering | 8 | 8
inv | BHR-10-VUA | Connector_IDC:IDC-Header_2x05_P2.54mm_Vertical | 2 | 2
inv | J104D2C12VDC.15S | Relay_THT:Relay_DPDT_Finder_30.22 | 8 | 8
jnc | BHR-10-VUA | Connector_IDC:IDC-Header_2x05_P2.54mm_Vertical | 4 | 32
Mem-esp | 10u | Capacitor_THT:CP_Radial_D10.0mm_P5.00mm | 1 | 3
Mem-esp | 100n | Capacitor_SMD:C_0805_2012Metric_Pad1.18x1.45mm_HandSolder | 4 | 12
Mem-esp | 10u | Capacitor_SMD:C_0805_2012Metric_Pad1.18x1.45mm_HandSolder | 1 | 3
Mem-esp | 4.7u | Capacitor_SMD:C_0805_2012Metric_Pad1.18x1.45mm_HandSolder | 1 | 3
Mem-esp | Conn_02x02_Odd_Even | Connector_PinHeader_2.54mm:PinHeader_2x02_P2.54mm_Vertical | 1 | 3
Mem-esp | BHR-10-VUA | Connector_IDC:IDC-Header_2x05_P2.54mm_Vertical | 2 | 6
Mem-esp | Conn_01x01 | Connector_PinHeader_2.54mm:PinHeader_1x01_P2.54mm_Vertical | 4 | 12
Mem-esp | 10k | Resistor_SMD:R_0805_2012Metric_Pad1.20x1.40mm_HandSolder | 21 | 63
Mem-esp | 2.2k | Resistor_SMD:R_0805_2012Metric_Pad1.20x1.40mm_HandSolder | 20 | 60
Mem-esp | BA7806CP-E2 | Package_TO_SOT_THT:TO-220-3_Vertical | 1 | 3
Mem-esp | ESP32-S3-DevKitC | PCM_Espressif:ESP32-S3-DevKitC | 1 | 3
Mem-esp | LTV-247 | Package_SO:SOP-16_4.4x10.4mm_P1.27mm | 5 | 15
Mem-esp | DRV8908 | Package_SO:HTSSOP-24-1EP_4.4x7.8mm_P0.65mm_EP3.4x7.8mm_Mask2.4x4.68mm_ThermalVias | 1 | 3
nor | US1D-A | Diode_SMD:D_SMA_Handsoldering | 16 | 16
nor | SMAJ14CA | Diode_SMD:D_SMA_Handsoldering | 8 | 8
nor | BHR-10-VUA | Connector_IDC:IDC-Header_2x05_P2.54mm_Vertical | 3 | 3
nor | J104D2C12VDC.15S | Relay_THT:Relay_DPDT_Finder_30.22 | 8 | 8
reg | 470uF | Capacitor_THT:CP_Radial_D10.0mm_P5.00mm | 8 | 24
reg | SMAJ14CA | Diode_SMD:D_SMA_Handsoldering | 9 | 27
reg | BHR-10-VUA | Connector_IDC:IDC-Header_2x05_P2.54mm_Vertical | 4 | 12
reg | Conn_01x01 | Connector_PinHeader_2.54mm:PinHeader_1x01_P2.54mm_Vertical | 1 | 3
reg | Conn_02x02_Odd_Even | Connector_PinHeader_2.54mm:PinHeader_2x02_P2.54mm_Vertical | 1 | 3
reg | J104D2C12VDC.15S | Relay_THT:Relay_DPDT_Finder_30.22 | 12 | 36
reg | 680R | Resistor_SMD:R_0805_2012Metric_Pad1.20x1.40mm_HandSolder | 8 | 24
reg | 47R | Resistor_SMD:R_0805_2012Metric_Pad1.20x1.40mm_HandSolder | 8 | 24
switch | 151053GS03000 | LED_THT:LED_D5.0mm_Clear | 8 | 48
switch | Conn_02x02_Odd_Even | Connector_PinHeader_2.54mm:PinHeader_2x02_P2.54mm_Vertical | 1 | 6
switch | BHR-10-VUA | Connector_IDC:IDC-Header_2x05_P2.54mm_Vertical | 1 | 6
switch | 750R | Resistor_SMD:R_0805_2012Metric_Pad1.20x1.40mm_HandSolder | 8 | 48
switch | SW_SPDT | cit-switch:AST_BST_13SNCQ_SPDT_ON_OFF_ON | 8 | 48
 |  |  |  | #N/A
 |  |  |  | #N/A
 |  |  |  | #N/A
 |  |  |  | #N/A
 |  |  |  | #N/A
 |  |  |  | #N/A
 |  |  |  | #N/A
 |  |  |  | #N/A
 |  |  |  | #N/A

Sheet: Pivot Table_Sheet1_1
Value | Footprint | Sum - Total qty | order number
100n | Capacitor_SMD:C_0805_2012Metric_Pad1.18x1.45mm_HandSolder | 12 | 1276-1180-1-ND
10k | Resistor_SMD:R_0805_2012Metric_Pad1.20x1.40mm_HandSolder | 63 | RMCF0805JT10K0CT-ND
10u | Capacitor_SMD:C_0805_2012Metric_Pad1.18x1.45mm_HandSolder | 3 | 490-18663-1-ND
 | Capacitor_THT:CP_Radial_D10.0mm_P5.00mm | 3
151053GS03000 | LED_THT:LED_D5.0mm_Clear | 88 | 732-5020-ND
2.2k | Resistor_SMD:R_0805_2012Metric_Pad1.20x1.40mm_HandSolder | 60 | RMCF0805FT2K20CT-ND
4.7u | Capacitor_SMD:C_0805_2012Metric_Pad1.18x1.45mm_HandSolder | 3 | 1276-6464-1-ND
470uF | Capacitor_THT:CP_Radial_D10.0mm_P5.00mm | 27 | 4191-EV1E471MP51012UCT-ND
47R | Resistor_SMD:R_0805_2012Metric_Pad1.20x1.40mm_HandSolder | 27 | 541-10540-1-ND
680R | Resistor_SMD:R_0805_2012Metric_Pad1.20x1.40mm_HandSolder | 25 | 541-10548-1-ND
750R | Resistor_SMD:R_0805_2012Metric_Pad1.20x1.40mm_HandSolder | 88 | 2019-SG73P2ATTD7500FCT-ND
BA7806CP-E2 | Package_TO_SOT_THT:TO-220-3_Vertical | 3 | BA7806CP-E2CT-ND
BHR-10-VUA | Connector_IDC:IDC-Header_2x05_P2.54mm_Vertical | 106 | 2057-BHR-10-VUA-ND
Conn_01x01 | Connector_PinHeader_2.54mm:PinHeader_1x01_P2.54mm_Vertical | 38 | 2057-PH1-01-UA-ND
Conn_01x02 | Connector_PinHeader_2.54mm:PinHeader_1x02_P2.54mm_Vertical | 2 | 2057-PH1-02-UA-ND
Conn_01x03 | Connector_PinHeader_2.54mm:PinHeader_1x03_P2.54mm_Vertical | 2 | 2057-PH1-03-UA-ND
Conn_01x08 | Connector_PinHeader_2.54mm:PinHeader_1x08_P2.54mm_Vertical | 1 | 2057-PH1-08-UA-ND
Conn_02x02_Odd_Even | Connector_PinHeader_2.54mm:PinHeader_2x02_P2.54mm_Vertical | 13 | 2057-PH2-04-UA-ND
D | Diode_SMD:D_SMA_Handsoldering | 11 | 4530-US1D-ACT-ND
DRV8908 | Package_SO:HTSSOP-24-1EP_4.4x7.8mm_P0.65mm_EP3.4x7.8mm_Mask2.4x4.68mm_ThermalVias | 3 | 296-DRV8908QPWPRQ1CT-ND
ESP32-S3-DevKitC | PCM_Espressif:ESP32-S3-DevKitC | 3 | 1965-ESP32-S3-DEVKITC-1-N8R2-ND
J104D2C12VDC.15S | Relay_THT:Relay_DPDT_Finder_30.22 | 124 | 2449-J104D2C12VDC.15S-ND
LTV-247 | Package_SO:SOP-16_4.4x10.4mm_P1.27mm | 15 | 160-2255-1-ND
SMAJ14CA | Diode_SMD:D_SMA_Handsoldering | 79 | SMAJ14CALFCT-ND
SW_SPDT | cit-switch:AST_BST_13SNCQ_SPDT_ON_OFF_ON | 48 | 2449-AST13SNCQ-ND
US1D-A | Diode_SMD:D_SMA_Handsoldering | 16 | 4530-US1D-ACT-ND
Total Result |  | 863
 | 22 socket header (for ESP module, 2 per esp-mem board) | 6 | S7020-ND
 | ribbon cable (roll) | 1 | 3M157850-100-ND
FCS-10-SG | connector assemblies (ribbon cable, 10 pin, with notch) | 100 | 2057-FCS-10-SG-ND
 | 2x20(?) pin header (for power rail) | 1 | 2057-PH2-20-UA-ND
 | 2x2 socket header (for power cables) | 16 | 732-61300421821-ND
 | digikey ruler | 1 | DKS-PCB-RULER-ND
 | wire black (per ft) | 10 | 1175-1007-18-1-2000-001-1-TD-DS-ND
 | wire red (per ft) | 10 | 1175-1007-18-1-2000-004-1-TD-DS-ND
 | Heat-shrink tube (4ft) | 1 | Q2F3X018B-ND
 | jumper wires (20x) | 3 | 1528-1960-ND

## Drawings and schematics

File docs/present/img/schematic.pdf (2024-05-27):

+

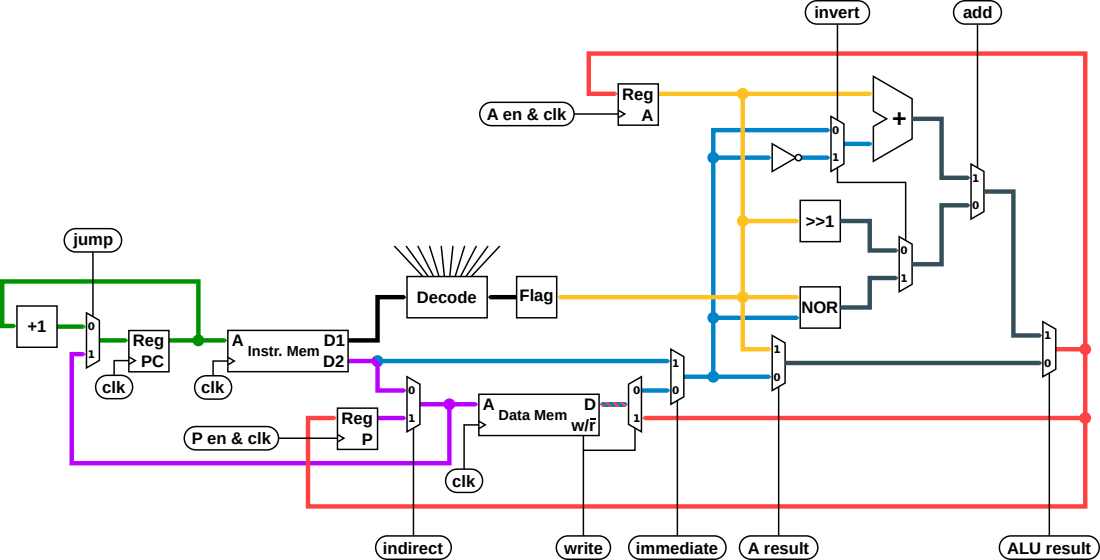
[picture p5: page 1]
Decode; Flag; Data Mem A; NOR; A en & clk; P en & clk; Reg A; clk; jump; indirect; write; immediate; A result; ALU result; invert; add; Reg P; Instr. Mem A; Reg PC

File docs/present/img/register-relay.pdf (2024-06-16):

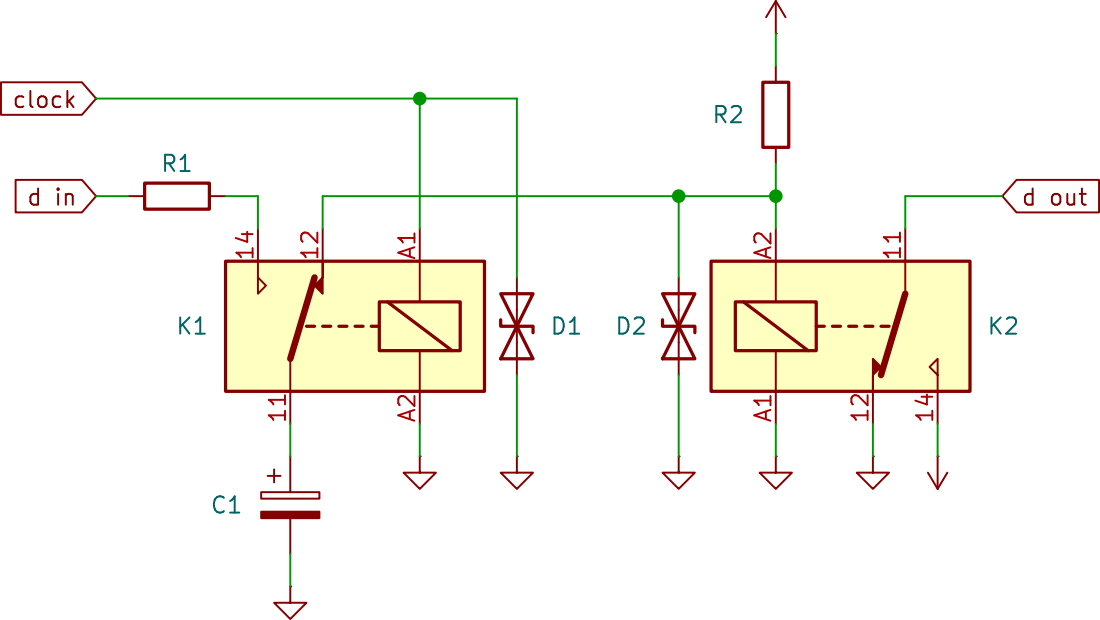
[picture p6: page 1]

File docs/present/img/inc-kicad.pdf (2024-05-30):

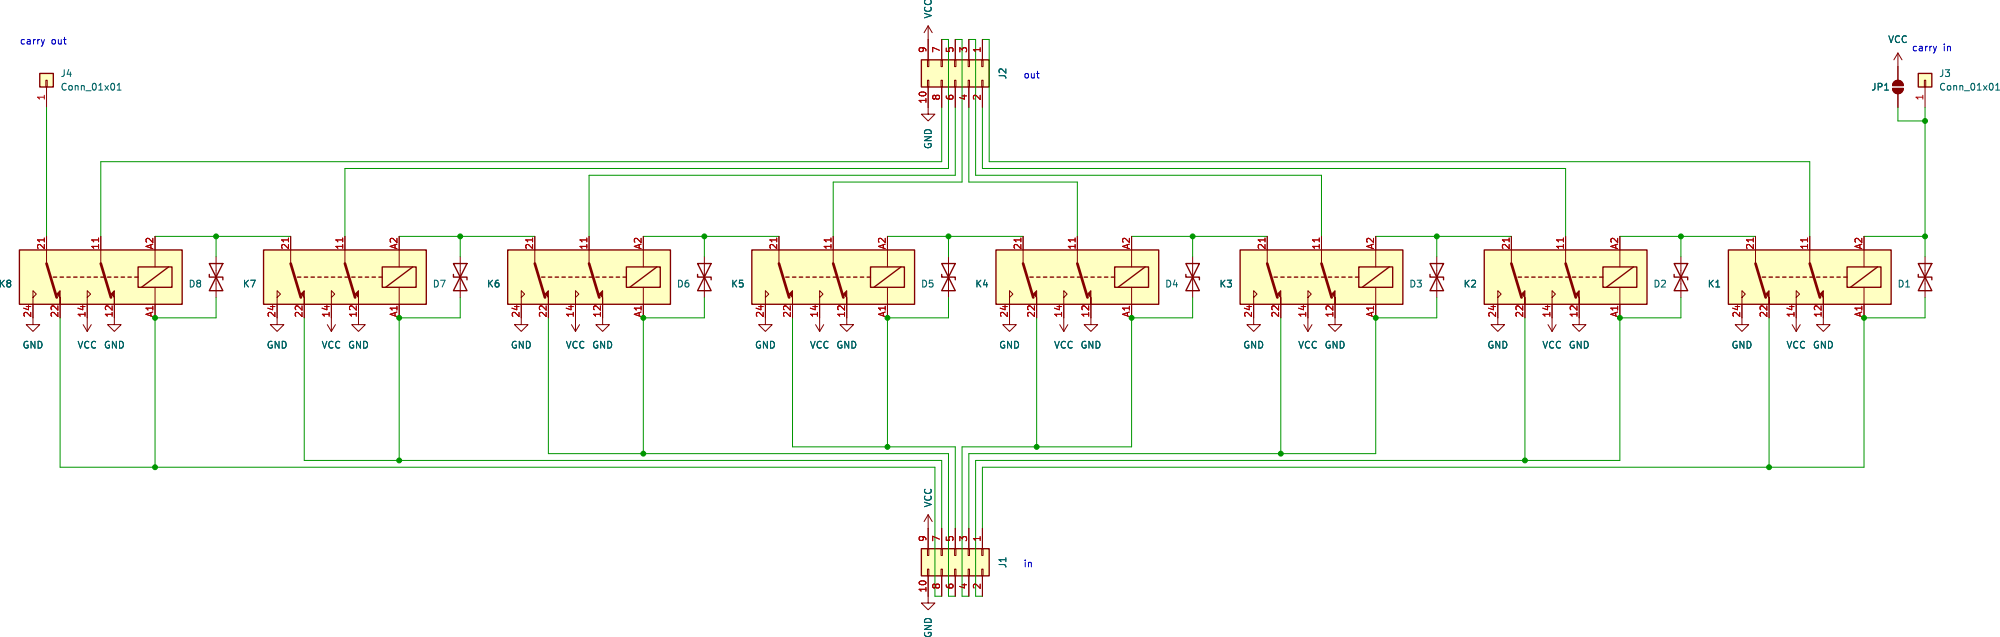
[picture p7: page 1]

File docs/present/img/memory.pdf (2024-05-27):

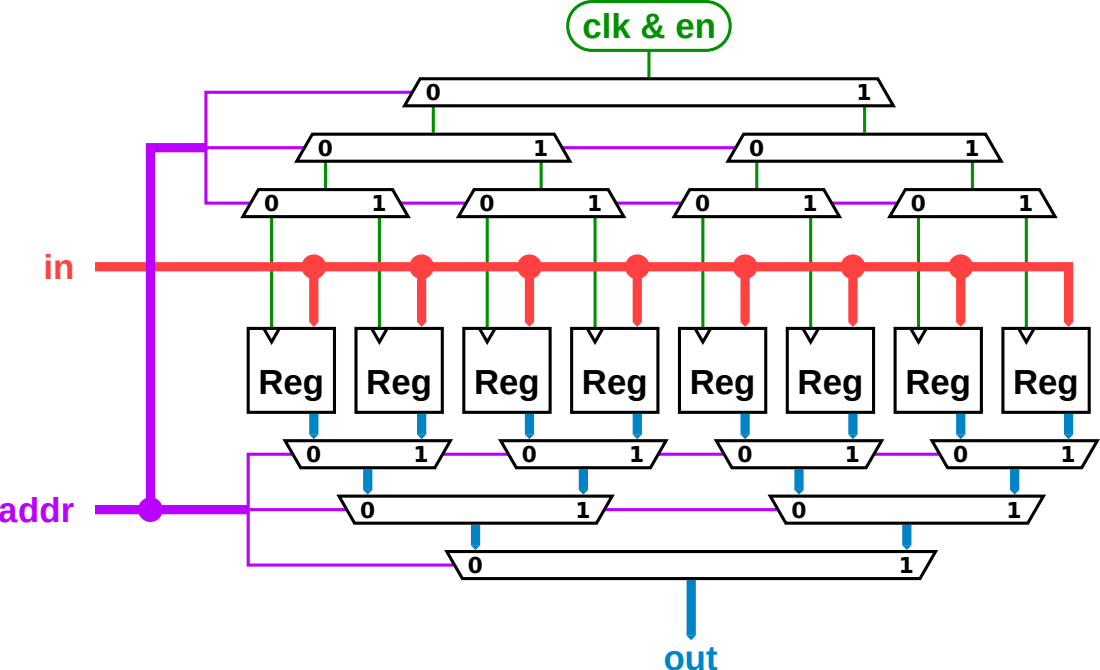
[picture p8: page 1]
clk & en; addr; out

Reg Reg Reg Reg

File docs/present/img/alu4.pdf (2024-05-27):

+

ab

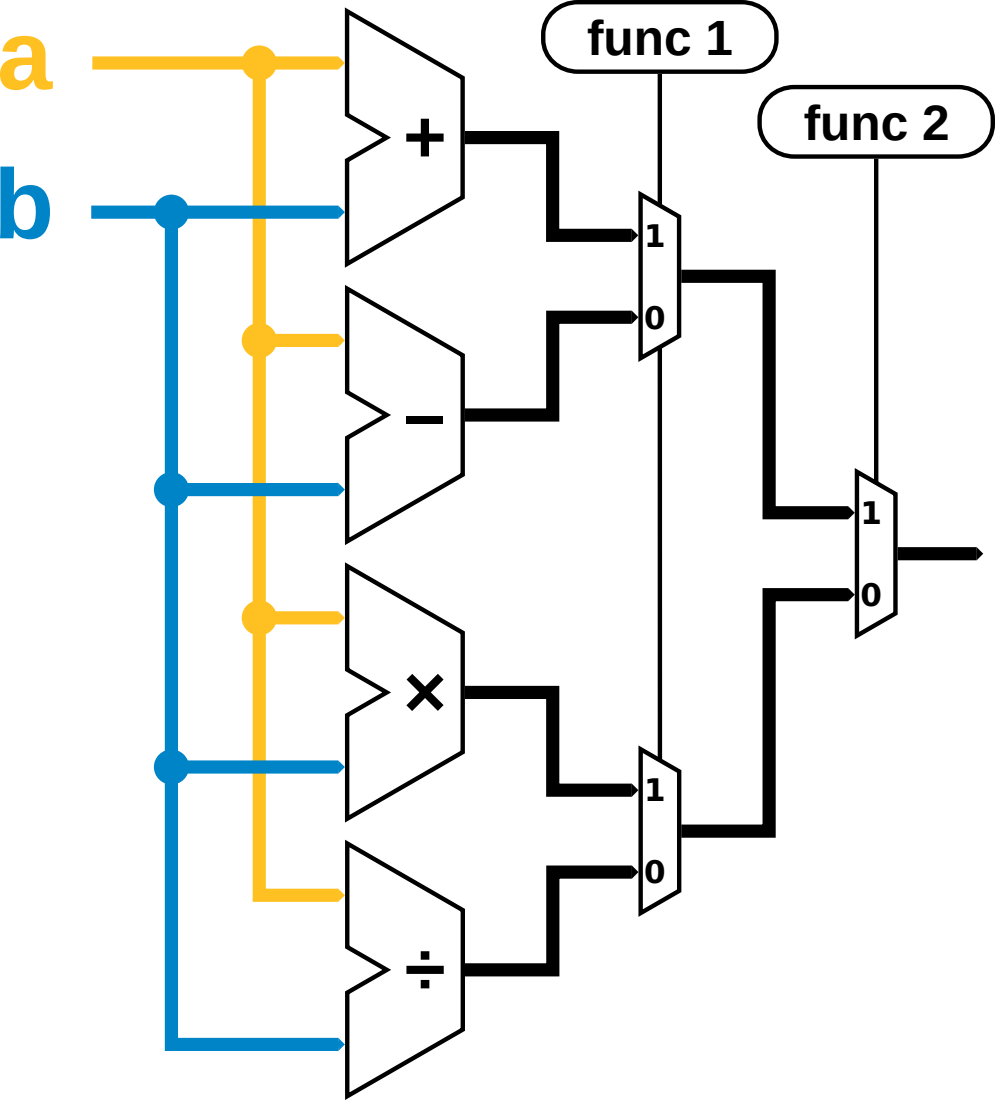
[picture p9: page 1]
func 1; func 2

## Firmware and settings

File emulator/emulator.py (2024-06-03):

#!/usr/bin/env python3

import argparse
from cmd import Cmd
import sys

# Bit widths of our memories
PROGRAM_SIZE = 1 << 8
PROGRAM_MAX = 1 << 16
DATA_SIZE = 1 << 8
DATA_MAX = 1 << 8

# Control bits for computational instructions
ADDRESS_SOURCE_BIT = 8
OPERAND_SOURCE_BIT = 9
ADD_BIT = 10
INVERT_BIT = 11
RESULT_SOURCE_1_BIT = 11
RESULT_SOURCE_2_BIT = 12
WRITE_A_BIT = 13
WRITE_P_BIT = 14
WRITE_MEMORY_BIT = 15
# ... and for jumps
CONDITIONAL_BIT = 9
CONDITION_1_BIT = 10
CONDITION_2_BIT = 11
CONDITION_INVERT_BIT = 12

# Shell stuff
USE_ANSI = True
if USE_ANSI:
    REVERSE_VIDEO = "\033[7m"
    NORMAL_VIDEO = "\033[m"
else:
    REVERSE_VIDEO = ""
    NORMAL_VIDEO = ""

class Machine:
    def __init__(self) -> None:
        self.program_memory: list[int] = [0x0000 for _ in range(PROGRAM_SIZE)]
        self.data_memory: list[int] = [0x00 for _ in range(DATA_SIZE)]

        self.program_counter: int = 0
        self.register_a: int = 0
        self.register_p: int = 0
        self.carry_flag: bool = False

        self.clock: int = 0


    def range_check(self, what: str, value: int, maximum: int) -> None:
        if value < 0 or value >= maximum:
            raise ValueError(f"{what} {value}/0x{value:x} is out of range (maximum is {maximum - 1}/0x{maximum - 1:x})")


    def store_program(self, address: int, data: int) -> None:
        self.range_check("address", address, PROGRAM_SIZE)
        self.range_check("data", data, PROGRAM_MAX)
        self.program_memory[address] = data


    def write_program(self, start: int, words: list[int]) -> None:
        # We range check the whole program beforehand so we don't end
        # up with half of it written to memory.
        self.range_check("program start", start, PROGRAM_SIZE)
        self.range_check("program end", start + len(words) - 1, PROGRAM_SIZE)
        for (address, data) in enumerate(words, start=start):
            self.store_program(address, data)


    def store_data(self, address: int, data: int) -> None:
        self.range_check("address", address, DATA_SIZE)
        self.range_check("data", data, DATA_MAX)
        self.data_memory[address] = data


    def write_data(self, start: int, words: list[int]) -> None:
        # We range check the whole data beforehand so we don't end
        # up with half of it written to memory.
        self.range_check("data start", start, DATA_SIZE)
        self.range_check("data end", start + len(words) - 1, DATA_SIZE)
        for (address, data) in enumerate(words, start=start):
            self.store_data(address, data)


    def zero_flag(self) -> bool:
        return self.register_a == 0


    def sign_flag(self) -> bool:
        return self.register_a & 0b10000000 != 0


    def odd_flag(self) -> bool:
        return self.register_a & 0b00000001 != 0


    def bitinvert(self, x) -> int:
        return ~x & 0xff


    def is_bit_set(self, value, bit_index) -> bool:
        return value & (1 << bit_index) != 0


    def step(self) -> None:
        instruction = self.program_memory[self.program_counter]
        if instruction & ((1 << WRITE_A_BIT) | (1 << WRITE_P_BIT) | (1 << WRITE_MEMORY_BIT)) == 0:
            self.step_jump(instruction)
        else:
            self.step_compute(instruction)

        self.clock += 1


    def step_compute(self, instruction) -> None:
        insn_address_source = self.is_bit_set(instruction, ADDRESS_SOURCE_BIT)
        insn_operand_source = self.is_bit_set(instruction, OPERAND_SOURCE_BIT)
        insn_add = self.is_bit_set(instruction, ADD_BIT)
        insn_invert = self.is_bit_set(instruction, INVERT_BIT)
        insn_result_source_1 = self.is_bit_set(instruction, RESULT_SOURCE_1_BIT)
        insn_result_source_2 = self.is_bit_set(instruction, RESULT_SOURCE_2_BIT)
        insn_write_a = self.is_bit_set(instruction, WRITE_A_BIT)
        insn_write_p = self.is_bit_set(instruction, WRITE_P_BIT)
        insn_write_memory = self.is_bit_set(instruction, WRITE_MEMORY_BIT)

        operand = instruction & 0xff
        address = self.register_p if insn_address_source else operand
        memory_out = 0 if insn_write_memory else self.data_memory[address]
        operand_in = operand if insn_operand_source else memory_out

        alu_in_2 = self.bitinvert(operand_in) if insn_invert else operand_in
        carry_in = 1 if insn_invert else 0
        adder_result = self.register_a + alu_in_2 + carry_in
        carry_out = adder_result > 0xff
        adder_result &= 0xff
        if insn_add:
            self.carry_flag = carry_out

        non_adder_result = self.bitinvert(self.register_a | alu_in_2) if insn_invert else self.register_a >> 1
        alu_result = adder_result if insn_add else non_adder_result

        intermediate_result = self.register_a if insn_result_source_1 else operand_in
        result = alu_result if insn_result_source_2 else intermediate_result

        if insn_write_a:
            self.register_a = result
        if insn_write_p:
            self.register_p = result
        if insn_write_memory:
            self.data_memory[address] = result

        self.program_counter += 1
        self.program_counter &= 0xff


    def step_jump(self, instruction) -> None:
        insn_address_source = self.is_bit_set(instruction, ADDRESS_SOURCE_BIT)
        insn_conditional = self.is_bit_set(instruction, CONDITIONAL_BIT)
        insn_condition_1 = self.is_bit_set(instruction, CONDITION_1_BIT)
        insn_condition_2 = self.is_bit_set(instruction, CONDITION_2_BIT)
        insn_condition_invert = self.is_bit_set(instruction, CONDITION_INVERT_BIT)

        operand = instruction & 0xff
        target = self.register_p if insn_address_source else operand

        if not insn_conditional:
            self.program_counter = target
        else:
            match (insn_condition_1, insn_condition_2):
                case (False, False):
                    flag = self.carry_flag
                case (False, True):
                    flag = self.sign_flag()
                case (True, False):
                    flag = self.zero_flag()
                case (True, True):
                    flag = self.odd_flag()

            # Jump if the flag in question is set and the jump
            # condition is not inverted or vice versa
            if flag != insn_condition_invert:
                self.program_counter = target
            else:
                self.program_counter += 1
                self.program_counter &= 0xff


class Shell(Cmd):
    intro = "This is the vis vitalis emulator. Type help or ? to list the commands.\n" \
        "To step the machine, you may also simply press enter on an empty prompt\n" \
        "Note: All numbers are hexadecimal by default. Prefix decimal numbers with \"0d\"\n"
    prompt = "> "

    def initialize(self):
        self.machine = Machine()
        self.hex_mode = True


    def to_int(self, string: str) -> int:
        if string.startswith("0d"):
            return int(string[2:], 10)
        elif string.startswith(("0b", "0B", "0o", "0O", "0x", "0X")):
            return int(string, 0)
        else:
            return int(string, 16)


    def do_exit(self, arg: str) -> bool:
        "exit the emulator"
        return True


    def do_EOF(self, arg: str) -> bool:
        "exit the emulator"
        print()
        return self.do_exit(arg)


    def do_pwrite(self, arg: str) -> None:
        "pwrite <start> <data ...>: Write <data ...> into program memory beginning at address <start>"
        try:
            [address_word, *data_words] = arg.split()
            address = self.to_int(address_word)
            data = list(map(self.to_int, data_words))
            self.machine.write_program(address, data)
        except ValueError as e:
            print(f"Failed: {e}")


    def do_dwrite(self, arg: str) -> None:
        "dwrite <start> <data ...>: Write <data ...> into data memory beginning at address <start>"
        try:
            [address_word, *data_words] = arg.split()
            address = self.to_int(address_word)
            data = list(map(self.to_int, data_words))
            self.machine.write_data(address, data)
        except ValueError as e:
            print(f"Failed: {e}")


    def load_from_file(self, arg: str, next_command: str) -> None:
        try:
            words = arg.split()
            filename = words[0]

            if len(words) == 1:
                start = "0"
            elif len(words) == 2:
                start = words[1]
            else:
                raise ValueError("too many arguments (expected 1 or 2)")

            contents = open(filename).read().replace("\n", " ")
            self.cmdqueue.append(f"{next_command} {start} {contents}")

        except Exception as e:
            print(f"Failed: {e}")


    def do_pload(self, arg: str) -> None:
        "pload <filename> <start>?: Load program memory from a file named <filename>. Begin at address <start>, or at address 0 if no <start> is given."
        self.load_from_file(arg, "pwrite")


    def do_dload(self, arg: str) -> None:
        "dload <filename> <start>?: Load data memory from a file named <filename>. Begin at address <start>, or at address 0 if no <start> is given."
        self.load_from_file(arg, "dwrite")


    def do_reg(self, arg: str) -> None:
        "reg <reg> <value>: Set register <reg> to value <value>. Register names are case-insensitive."
        try:
            words = arg.split()
            regname = words[0].casefold()
            value = self.to_int(words[1])

            match regname:
                case "a":
                    self.machine.register_a = value
                case "p":
                    self.machine.register_p = value
                case "pc":
                    self.machine.program_counter = value
                case _:
                    raise ValueError(f"{regname} is not a valid register name")

        except Exception as e:
            print(f"Failed: {e}")


    def do_reset(self, arg: str) -> None:
        "reset: Reset program counter and clock to 0"
        self.machine.program_counter = 0
        self.machine.clock = 0


    def do_show(self, arg: str) -> None:
        "show: Show current machine state"

        print("PROGRAM MEMORY (highlight: PC) ================================================")
        for (i, word) in enumerate(self.machine.program_memory):
            if i == self.machine.program_counter:
                print(REVERSE_VIDEO, end="")
            print(f"{word:04x}", end="")
            if i == self.machine.program_counter:
                print(NORMAL_VIDEO, end="")
            if i % 16 == 15:
                print()
            else:
                print(" ", end="")
        print("===============================================================================")
        print()
        print("DATA MEMORY (highlight: P) ====================")
        for (i, word) in enumerate(self.machine.data_memory):
            if i == self.machine.register_p:
                print(REVERSE_VIDEO, end="")
            print(f"{word:02x}", end="")
            if i == self.machine.register_p:
                print(NORMAL_VIDEO, end="")
            if i % 16 == 15:
                print()
            else:
                print(" ", end="")
        print("===============================================")
        print()
        print(f"A     = {self.machine.register_a:02x}")
        print(f"P     = {self.machine.register_p:02x}")
        print(f"PC    = {self.machine.program_counter:02x}")
        print("FLAGS = ", end="")
        print("ZERO "  if self.machine.zero_flag() else "     ",  end="")
        print("SIGN "  if self.machine.sign_flag() else "     ",  end="")
        print("ODD "   if self.machine.odd_flag()  else "    ",   end="")
        print("CARRY " if self.machine.carry_flag  else "      ")
        print()
        print(f"CLOCK = {self.machine.clock}")


    def do_step(self, arg: str) -> None:
        "step the machine by one instruction. Also the default action if no command is given."
        self.machine.step()
        self.cmdqueue.append("show")


    def emptyline(self) -> None:
        return self.do_step("")


if __name__ == "__main__":
    parser = argparse.ArgumentParser()
    parser.add_argument("images", nargs="*", default=None)
    args = parser.parse_args()

    shell = Shell()
    shell.initialize()

    if len(args.images) > 2:
        print("Too many image files were given. Expecting either:")
        print("  - Just a program image")
        print("  - First a program image, then a data image")
        sys.exit(1)

    elif len(args.images) == 2:
        [program_image, data_image] = args.images
        shell.cmdqueue.append(f"pload {program_image}")
        shell.cmdqueue.append(f"dload {data_image}")

    elif len(args.images) == 1:
        [program_image] = args.images
        shell.cmdqueue.append(f"pload {program_image}")

    shell.cmdloop()

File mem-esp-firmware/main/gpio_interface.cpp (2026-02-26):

#include "gpio_interface.hpp"

#include <algorithm>
#include <ranges>

#include <esp_log.h>

const char *TAG = "GPIO_INTERFACE";

static constexpr unsigned ADDRESS_CHANGE_DELAY = 100 / portTICK_PERIOD_MS;
static constexpr unsigned WRITE_CYCLE_SAMPLE_TIME = 20 / portTICK_PERIOD_MS;

static constexpr unsigned MIN_WRITE_SAMPLES = 5;

static void IRAM_ATTR reset_timer_isr(void *arg)
{
	TimerHandle_t *timer = (TimerHandle_t*) arg;

	int task_should_yield = false;
	if (xTimerResetFromISR(*timer, &task_should_yield) != pdPASS) {
		// TODO emergency stop
		abort();
	}

	if (task_should_yield == pdTRUE) {
		portYIELD_FROM_ISR();
	}
}

void GpioInterface::address_change_expired(TimerHandle_t timer)
{
	GpioInterface *_this = (GpioInterface*) pvTimerGetTimerID(timer);
	_this->on_address_change();
}

void GpioInterface::on_address_change()
{
	uint8_t new_address = 0;

	for (gpio_num_t address_pin : std::ranges::reverse_view(address_pins)) {
		new_address <<= 1;
		new_address |= gpio_get_level(address_pin);
	}

	listener->on_address_change(new_address);
}

void IRAM_ATTR GpioInterface::write_pin_change_isr(void *arg)
{
	GpioInterface *_this = (GpioInterface*) arg;

	int task_should_yield = false;
	int level = gpio_get_level(_this->write_pin);

	if (level == 0) {
		// Going from write to read means turning on the
		// data output. Delay this until the muxes have switched.
		if (xTimerResetFromISR(_this->write_pin_change_timer, &task_should_yield) != pdPASS) {
			// TODO emergency stop
			abort();
		}
	} else {
		// Going from read to write means shutting off the
		// data output. Do that immediately.
		if (xTimerPendFunctionCallFromISR(
			    on_write_pin_change, _this, level, &task_should_yield) != pdPASS) {
			// TODO emergency stop
			abort();
		}
	}

	if (task_should_yield == pdTRUE) {
		portYIELD_FROM_ISR();
	}
}

void GpioInterface::write_pin_change_expired(TimerHandle_t timer)
{
	GpioInterface *_this = (GpioInterface*) pvTimerGetTimerID(timer);
	int level = gpio_get_level(_this->write_pin);
	on_write_pin_change(_this, level);
}

void GpioInterface::on_write_pin_change(void *arg1, uint32_t level)
{
	GpioInterface *_this = (GpioInterface*) arg1;
	RwState state = (level == 1) ? RwState::WRITE : RwState::READ;
	_this->listener->on_write_pin_change(state);
}

void GpioInterface::write_sample_expired(TimerHandle_t timer)
{
	GpioInterface *_this = (GpioInterface*) pvTimerGetTimerID(timer);
	_this->on_write_sample();
}

void GpioInterface::on_write_sample()
{
	int clock_pin_state = gpio_get_level(clock_pin);
	int write_pin_state = gpio_get_level(write_pin);

	if (clock_pin_state == 1 && write_pin_state == 1) {
		for (int i = 0; i < DATA_IN_BITS; i++) {
			int level = gpio_get_level(data_pins.at(i));
			write_samples.at(i) <<= 1;
			write_samples.at(i) |= level;
		}
		n_write_samples++;

		if (xTimerReset(write_sample_timer, portMAX_DELAY) != pdPASS) {
			ESP_LOGE(TAG, "write_sample_timer is stuck");
			// TODO emergency stop
			abort();
		}

	} else {
		// Write cycle is finished
		// But only execute the write if we have seen enough samples,
		// i.e. clock has been high for long enough
		ESP_LOGD(TAG, "%u samples", n_write_samples);

		if (n_write_samples >= MIN_WRITE_SAMPLES) {
			uint8_t data = 0;

			unsigned limit = std::min(CHAR_BIT * sizeof(uint32_t), n_write_samples) / 2;

			for (int i = 0; i < DATA_IN_BITS; i++) {
				uint32_t sample = write_samples.at(i);

				if (__builtin_popcount(sample) > limit) {
					data |= 1 << i;
				}
			}

			listener->on_write_cycle_complete(data);
		}

		for(uint32_t &sample : write_samples) {
			sample = 0;
		}
		n_write_samples = 0;
	}
}
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

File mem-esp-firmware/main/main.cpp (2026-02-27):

#include <stdio.h>
#include <string.h>

#include <ranges>

#include <driver/spi_master.h>
#include <esp_console.h>
#include <esp_log.h>
#include <linenoise/linenoise.h>

#include "drv8908.hpp"
#include "gpio_assignment.hpp"
#include "gpio_interface.hpp"
#include "memory.hpp"
#include "memory_controller.hpp"

static const char *TAG = "MAIN";

class GpioDebug
	: public GpioListener {
	virtual void on_address_change(uint8_t new_address) {
		ESP_LOGI(TAG, "address change 0x%02x\n", new_address);
	}
	virtual void on_write_pin_change(RwState new_state) {
		if (new_state == RwState::READ) {
			ESP_LOGI(TAG, "read\n");
		} else {
			ESP_LOGI(TAG, "write\n");
		}
	}
	virtual void on_write_cycle_complete(uint8_t new_data) {
		ESP_LOGI(TAG, "data write 0x%02x\n", new_data);
	}
	virtual void invalidate() {
		ESP_LOGI(TAG, "invalidate\n");
	}
};

static Memory mem;
static MemoryController *controller;
static Drv8908 *driver;

static int handle_clear_cmd(int argc, char **argv)
{
	for (int i = 0; i < MEMORY_SIZE; i++) {
		mem.write(i, 0);
	}

	return 0;
}

static int handle_write_cmd(int argc, char **argv)
{
	if (argc != 3) {
		printf("Wrong number of arguments (2 expected)\n");
		return 2;
	}

	uint8_t address;
	uint16_t data;

	int success = sscanf(argv[1], "%hhx", &address);
	if (success != 1) {
		printf("Cannot parse address\n");
		return 2;
	}
	success = sscanf(argv[2], "%hx", &data);
	if (success != 1) {
		printf("Cannot parse address\n");
		return 2;
	}

	mem.write(address, data);
	controller->invalidate();

	return 0;
}

static int handle_load_cmd(int argc, char **argv)
{
	int addr = 0;
	char *line = NULL;

	while (addr < MEMORY_SIZE) {
		line = linenoise("");

		if (line == NULL || strcmp(line, "") == 0) {
			goto exit_ok;
			break;
		}

		char *argv[257];

		size_t n_args = esp_console_split_argv(line, argv, 257);

		for (int i = 0; i < n_args; i++) {
			uint16_t data = 0;
			int success = sscanf(argv[i], "%hx", &data);
			if (success != 1) {
				printf("Could not parse value \"%s\"\n", argv[i]);
				goto exit_error;
			}

			mem.write(addr, data);
			addr++;

			if (addr >= MEMORY_SIZE && i < n_args - 1) {
				printf("Warning: extra data at end of line\n");
				goto exit_ok;
			}
		}

		free(line);
	}

	controller->invalidate();
	return 0;

exit_ok:
	free(line);
	controller->invalidate();
	return 0;

exit_error:
	free(line);
	controller->invalidate();
	return 2;
}

static int handle_dump_cmd(int argc, char **argv)
{
	std::string contents = mem.show();
	printf("%s\n", contents.c_str());

	return 0;
}

static int handle_reset_fault_cmd(int argc, char **argv)
{
	driver->reset_fault();
	return 0;
}

extern "C" void app_main(void)
{
	printf("hello world\n");

	for (int i = 0; i < MEMORY_SIZE; i++) {
		mem.write(i, (3 * i) % MEMORY_SIZE);
	}

	GpioDebug gpio_debug;

	spi_bus_config_t spi_config {
		.mosi_io_num = GpioAssignment::sdi_out,
		.miso_io_num = GpioAssignment::sdi_in,
		.sclk_io_num = GpioAssignment::sdi_clock,
		.max_transfer_sz = 6,
	};

	ESP_ERROR_CHECK(spi_bus_initialize(SPI2_HOST, &spi_config, SPI_DMA_DISABLED));

	Drv8908 output_driver(SPI2_HOST,
	                      GpioAssignment::driver_chip_select,
	                      GpioAssignment::driver_fault_in);
	driver = &output_driver;

	MemoryController mc(mem, output_driver);
	controller = &mc;

	GpioInterface gpios(
		GpioAssignment::address_in,
		GpioAssignment::data_in,
		GpioAssignment::clock_in,
		GpioAssignment::write_not_read_in,
		&mc
		);


	esp_console_dev_uart_config_t uart_config {
		.channel = 0,
		.baud_rate = 115200,
		.tx_gpio_num = -1,
		.rx_gpio_num = -1,
	};
	esp_console_repl_config_t repl_config {
		.max_history_len = 10,
		.history_save_path = NULL,
		.task_stack_size = 4096,
		.task_priority = tskIDLE_PRIORITY,
		.prompt = "mem> ",
	};
	esp_console_repl_t *repl;

	ESP_ERROR_CHECK(esp_console_new_repl_uart(&uart_config, &repl_config, &repl));

	esp_console_cmd_t clear_cmd {
		.command = "clear",
		.help = "Clear memory (reset to 0x00)",
		.hint = "",
		.func = handle_clear_cmd,
		.argtable = NULL,
	};
	esp_console_cmd_register(&clear_cmd);

	esp_console_cmd_t write_cmd {
		.command = "w",
		.help = "Write into memory",
		.hint = "",
		.func = handle_write_cmd,
		.argtable = NULL,
	};
	esp_console_cmd_register(&write_cmd);

	esp_console_cmd_t load_cmd {
		.command = "load",
		.help = "Load a memory image",
		.hint = "",
		.func = handle_load_cmd,
		.argtable = NULL,
	};
	esp_console_cmd_register(&load_cmd);

	esp_console_cmd_t dump_cmd {
		.command = "dump",
		.help = "dump memory contents",
		.hint = "",
		.func = handle_dump_cmd,
		.argtable = NULL,
	};
	esp_console_cmd_register(&dump_cmd);

	esp_console_cmd_t reset_fault_cmd {
		.command = "reset_fault",
		.help = "reset driver fault flag",
		.hint = "",
		.func = handle_reset_fault_cmd,
		.argtable = NULL,
	};
	esp_console_cmd_register(&reset_fault_cmd);

	printf("Setup complete\n");

	esp_console_start_repl(repl);
	while(1) {
		vTaskDelay(1000 / portTICK_PERIOD_MS);
	}
}

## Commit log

2018-03-24 Initial dump.
    [8mux.kicad_pcb, 8mux.sch, inc.kicad_pcb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]
2018-03-24 Finish inc (now also with carry out).
    [inc.kicad_pcb, inc.sch]
2018-03-25 Add adder.
    [add.kicad_pcb, add.sch]
2018-11-13 Commit everything before the new KiCad eats my schematics.
    [add.kicad_pcb, add.sch, reg.kicad_pcb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]
2018-12-27 Update to new Kicad, finish reg.
    [add.kicad_pcb, inc.kicad_pcb, inc.sch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]
2018-12-28 Add zero component.
    [zero.kicad_pcb, zero.sch]
2018-12-28 Add flyback diode to zero.
    [zero.kicad_pcb, zero.sch]
2019-01-11 Many things happened at 35C3.
    [decode.kicad_pcb, decode.sch, zero.kicad_pcb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]
2019-02-09 Change opcodes (jumps from rediscovered notes).
    [decode.kicad_pcb, decode.sch]
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2019-10-31 Rescue adder.
    [add.sch]
2020-05-22 reg: Route missing GND connection.
    [reg.kicad_pcb]
2023-12-30 Begin new parts, add template.
    [template.kicad_pcb, template.kicad_sch]
2023-12-30 Git-ignore (old) parts directory, commit final changes there.
    [decode.kicad_pcb, reg.kicad_pcb]
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2023-12-31 template: import design rules.
    [template.kicad_pcb, template.kicad_sch]
2023-12-31 Add 8mux part.
    [8mux.kicad_pcb, 8mux.kicad_sch]
2024-01-02 8mux: Even out relay placement.
    [8mux.kicad_pcb]
2024-01-02 add: Fix J1/J2 labels.
    [add.kicad_pcb]
2024-01-03 8mux, add: Add dimensions, move to User.Drawings layer.
    [8mux.kicad_pcb, add.kicad_pcb]
2024-01-03 Add inc.
    [inc.kicad_pcb, inc.kicad_sch]
2024-01-20 Begin reg module.
    [reg.kicad_pcb, reg.kicad_sch]
2024-01-21 Finish reg.
    [reg.kicad_pcb]
2024-01-22 Add flags.
    [flags.kicad_pcb, flags.kicad_sch]
2024-01-23 Reverse clock polarity.
    It's more convenient to have the registers sample the input while the
    clock is high, and latch it to the output on the falling edge. That way,
    a register whose clock input is kept low or Z will not change (otherwise,
    we would have to keep idle registers' clock inputs high).
    [reg.kicad_pcb, reg.kicad_sch]
2024-01-26 Add decoder schematics and begin layout (it's terrible).
    [decode.kicad_pcb, decode.kicad_sch]
2024-01-30 Layout decoder.
    [decode.kicad_pcb, decode.kicad_sch]
2024-01-30 decode: Position silkscreen labels, strengthen flags's ground connection.
    [decode.kicad_pcb]
2024-01-30 Add jnc.
    [jnc.kicad_pcb, jnc.kicad_sch]
2024-01-31 Add nor.
    [nor.kicad_pcb, nor.kicad_sch]
2024-01-31 Add inv.
    [inv.kicad_pcb, inv.kicad_sch]
2024-01-31 Add (wired) or.
    [or.kicad_pcb, or.kicad_sch]
2024-02-15 Begin work on "memory" interface.
    [mem.kicad_pcb, mem.kicad_sch]
2024-03-03 Finish mem schematics and most of its layout.
    [mem.kicad_pcb, mem.kicad_sch]
2024-03-05 Add ESP32-based memory unit.
    [mem-esp.kicad_pcb, mem-esp.kicad_sch]
2024-03-05 reg: Clarify labels.
    [reg.kicad_pcb]
2024-03-09 Finish layouting mem-esp.
    [mem-esp.kicad_pcb, mem-esp.kicad_sch]
2024-03-09 mem-esp: Fix warnings.
    [mem-esp.kicad_pcb, mem-esp.kicad_sch]
2024-03-13 Change all two-pin headers for control + ground to control only.
    This is to prevent accidental short circuits when they are plugged in the
    wrong way.
    [decode.kicad_pcb, decode.kicad_sch, flags.kicad_pcb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]
2024-03-13 decode: Move TP1 to join the others.
    [decode.kicad_pcb]
2024-03-13 mem-esp: Label power supply header.
    [mem-esp.kicad_pcb]
2024-03-13 Add placeholders for JLC order number.
    [8mux.kicad_pcb, add.kicad_pcb, decode.kicad_pcb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]
2024-03-24 Add a "title" label to all parts.
    [8mux.kicad_pcb, add.kicad_pcb, decode.kicad_pcb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]
2024-03-24 Fix connector values: change names from 2 rows to 1 row.
    [decode.kicad_sch, flags.kicad_sch, inc.kicad_sch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]
2024-03-24 mem-esp: Change to a THT power regulator for better heat dissipation.
    [mem-esp.kicad_pcb, mem-esp.kicad_sch]
2024-03-29 Add display component.
    [disp.kicad_pcb, disp.kicad_sch]
2024-03-29 mem-esp: Change capacitor behind LDO to a simpler part.
    [mem-esp.kicad_sch]
2024-03-29 Add switch component.
    [switch.kicad_pcb, switch.kicad_sch]
2024-03-30 Add clk component.
    [clk.kicad_pcb, clk.kicad_sch]
2024-03-30 Bump to KiCAD version 8.
    [8mux.kicad_pcb, 8mux.kicad_sch, add.kicad_pcb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]
2024-03-30 clk: Add trimming resistors.
    [clk.kicad_pcb, clk.kicad_sch]
2024-03-30 Perform BOM export (changes some project settings).
    [nor.kicad_sch]
2024-03-30 Add order spreadsheets.
    [digikey-order.ods, total.ods]
2024-03-31 Add power connector to nor gate for better GND distribution.
    [nor.kicad_pcb, nor.kicad_sch]
2024-04-02 decode: Also provide !invert control signal as carry in for the adder, provide 4 pins for every control signal.
    [decode.kicad_pcb, decode.kicad_sch]
2024-04-02 Changes made by JLCPCB fabrication plugin.
    [8mux.kicad_pcb, add.kicad_pcb, clk.kicad_pcb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]
2024-04-12 mem-esp: Add second output, so that the instruction memory only needs one module.
    [mem-esp.kicad_pcb, mem-esp.kicad_sch]
2024-04-12 reg: Note error in calculation.
    [reg.kicad_sch]
2024-04-12 mem-esp: Remove violating silkscreen line.
    [mem-esp.kicad_pcb]
2024-04-14 Add signatures to some boards.
    [add.kicad_pcb, decode.kicad_pcb, mem-esp.kicad_pcb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]
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2024-04-21 assembler: Add missing "shrs" instruction (shift right and store).
2024-04-21 assembler: Various small improvements:
    - Print messages to stdout
    - Add a hint about reading from stdin
    - Add help text to -o/--output-file
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2024-04-22 firmware: Fix interface of transmit_two_chips.
    [drv8908.cpp]
2024-04-25 assembler: work around paste bug in screen and/or the console.
2024-04-26 inc: Fix inverted output.
    [inc.kicad_pcb, inc.kicad_sch]
2024-04-26 mem-esp: Clarify GPIO requirements.
    [mem-esp.kicad_sch]
2024-04-26 switch: Fix footprint so that the larger pins fit.
    [switch.kicad_pcb]
2024-04-28 Reverse instruction encoding. Turns out the decoder is the wrong way round. Ooops...
    [emulator.py]
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2024-04-28 Fix/add measurements of the remaining parts.
    [clk.kicad_pcb, jnc.kicad_pcb, mem-esp.kicad_pcb]
2024-04-28 firmware: Invalidate memory contents after a write from the console, and then refresh the driver output.
2024-04-30 mem-esp: Add solder jumper to connect SPI if the second driver is not populated.
    [mem-esp.kicad_pcb, mem-esp.kicad_sch]
2024-04-30 inc: Add solder jumper for stanalone operation (carry in = 1).
    [inc.kicad_pcb, inc.kicad_sch]
2024-05-04 Add "r2" to updated PCBs.
    [inc.kicad_pcb, switch.kicad_pcb]
2024-05-04 Add shr (shift right) module.
    [shr.kicad_pcb, shr.kicad_sch]
2024-05-12 assembler: Change labels to the usual syntax ("<name>:" at the start of a line).
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2024-06-01 mem-esp-firmware: Report driver faults and add a command to (manually) clear them.
2024-06-03 reg: Correct "latching" coils' voltage dividers (finally).
    [reg.kicad_sch]
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2024-06-03 Remove unfinished STM-based memory controller PCB.
    [mem.kicad_pcb, mem.kicad_sch]
2024-10-06 tk: ui_to_machine: Improve error reporting.
    [tk.py]
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2026-02-26 firmware: Delay write->read transition.
    In some cases, the board is too fast to turn on its outputs after a change
    from memory write to memory read. This can cause an overcurrent condition
    if the mux has not switched yet. Looks like the mux is getting old and
    slowing down...
    [gpio_interface.cpp]
2026-02-27 firmware: Fix double-free when loading the whole memory.
    [main.cpp]
